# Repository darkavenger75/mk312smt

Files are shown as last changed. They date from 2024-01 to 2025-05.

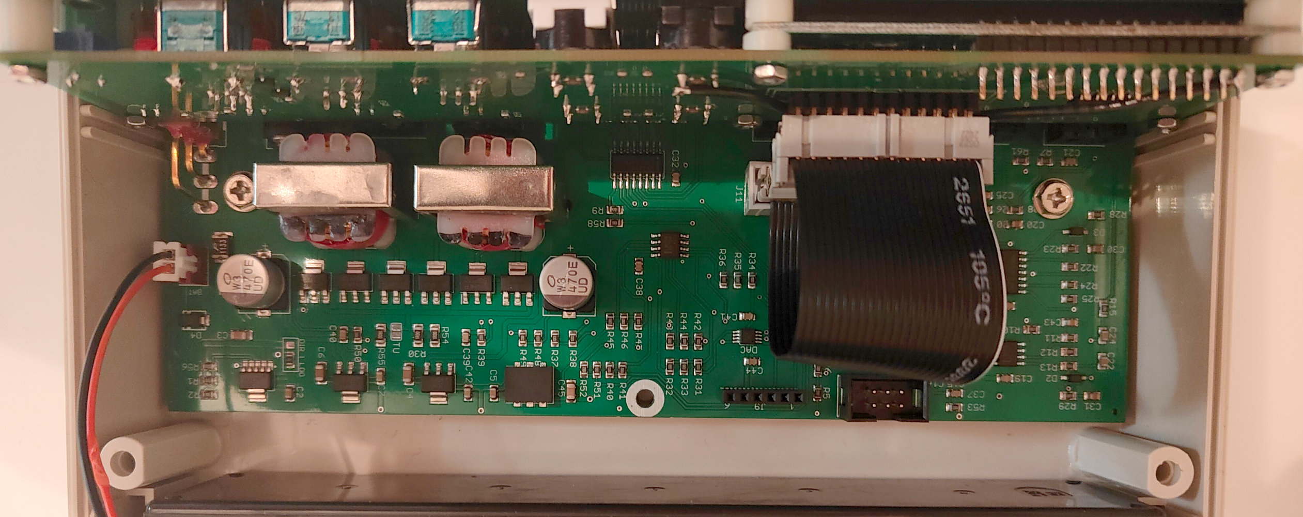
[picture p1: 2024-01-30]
images/mk312smt_int2.jpg

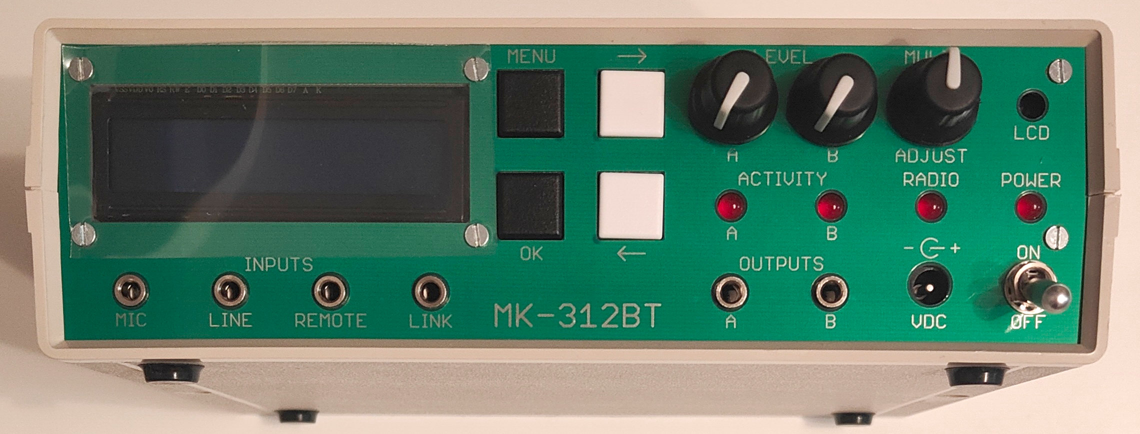
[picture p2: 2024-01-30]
images/mk312smt_front.jpg

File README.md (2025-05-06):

# mk-312 smt

## Introduction

A SMT version of the mk312-bt with several improvements

- More modern and efficient components in the power and output stage
- Input buttons more interference-proof to avoid the ATmega crashing
- And the best thing: someone like JLCPCB can do the assembly for you, you only need to add a few through-hole components and fit everything into the case. 

Main and control PCB are compatible with the THT versions, so that you can replace just one of them and keep the other PCB.

## Board ordering instructions 

PCB
- Default settings by JLCPCB work fine. Feel free to choose different color, etc. Lead-free recommended for the sake of the environment.

Assembly
- Economic, Bottom side (control PCB) / Top side (main PCB), as many PCBs as you wish. "Confirm Parts Placement" recommended. 
- Automatic selection of parts after uploading BOM and CPL worked well, but better check for obvious errors here and in part placement. 
- BOMs contain all components, including the THT ones. If you want to place the THT parts yourself just deselect them.

## Parts ordering information

You will in addition require
- Anything not on the PCB itself (button covers, knobs for pots, display + pin header).
- Any part your manufacturer did not have in stock. In case of JLCPCB this means especially the 42TU200 or 42TL004 transformers. Other parts missing you might pre-order to avoid additional effort. 
- 2x12P ribbon cable with connectors.
- A lead-acid battery of your choice. You can alternatively use a 12V LiFePO4 battery (with BMS), for that you need a matching charger (instead of the 15V power supply) and have to move the "jumper" (0R resistor) from "LDO" to "DIR" position to skip the voltage regulator. If you plan to use a LiFePO4 battery from the beginning (making the device much lighter) you can move the 0R resistor already when ordering and leave out V_REG (TPS73801), R1, R2, C2, C3, D1 from the beginning. These changes have been implemented in V2x which are now LiFePO4 only. 

## Board assembly Instructions

Nothing special here, just add the THT parts missing and mount the control panel to the front panel.

## Firmware

The firmware has not been modified, for instructions see the "firmware" folder. 

## Case

Fits in the stadard PACTEC case, see original BOM. 

## Update

- If the logic-level MOSFET IRLL2705 is not in stock at JLCPCB, it can be replaced by ZXMN4A06GTA or NDT3055L.
- The 5V DC-DC converter K7805MT-500R4 is no longer available. A version with a THT version has been added.
- If you like to keep using your 15V power supply with the LiFePO4 battery pack you can use V2b of the main PCB and the charger daughterboard.

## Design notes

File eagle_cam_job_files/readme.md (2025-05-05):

Please find the files required for PCB production and assembly here.
Do not forget the components (e.g. buttons and display) for the top side of the control PCB.
V1.3 Front Panel has a bit smaller cutout for the display, leaving less a gap. A display with outer dimensions 24*71 mm (many low-cost ones) fits. There are slightly larger displays, e.g. from Newhaven which are 26.5 mm high. Use version V1.3L for those.

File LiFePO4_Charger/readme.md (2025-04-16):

Daughterboard for the V2b main PCB.
LiFePO4 charger for the 4s battery pack so you can keep using your 15V power supply instead of using an external charger.

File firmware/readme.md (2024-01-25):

# MK312-BT Firmware

1. Set fuses for external 8 MHz crystal:
   
   avrdude -c usbasp-clone -p m16 -U lfuse:w:0xFF:m -U hfuse:w:0xD9:m
   
2. Flash any of the two firmware files, e.g. by

   avrdude -c usbasp-clone -p m16 -U "flash:w:HelloFriend.bin"

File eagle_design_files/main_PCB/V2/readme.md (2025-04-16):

5V DC-DC converter replaced by PTH version because of much better availability.
Version 2a with lower cost connectors and power switch. Version 2b has a connector for the LiFePO4 charger daughterboard.

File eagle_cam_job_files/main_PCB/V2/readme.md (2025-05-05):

5V DC-DC converter replaced by PTH version because of much better availability.
Version 2a with lower cost connectors and power switch (normally in stock at JLCPCB).
Version 2b has a connector for the LiFePO4 charger daughterboard.

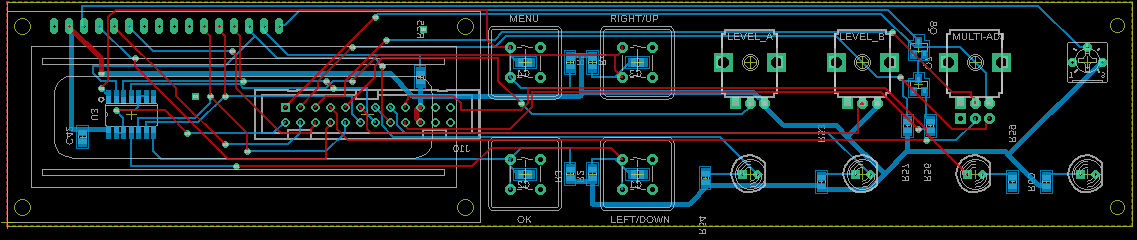
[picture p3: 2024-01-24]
eagle_design_files/control_PCB/mk312_control_Top.png

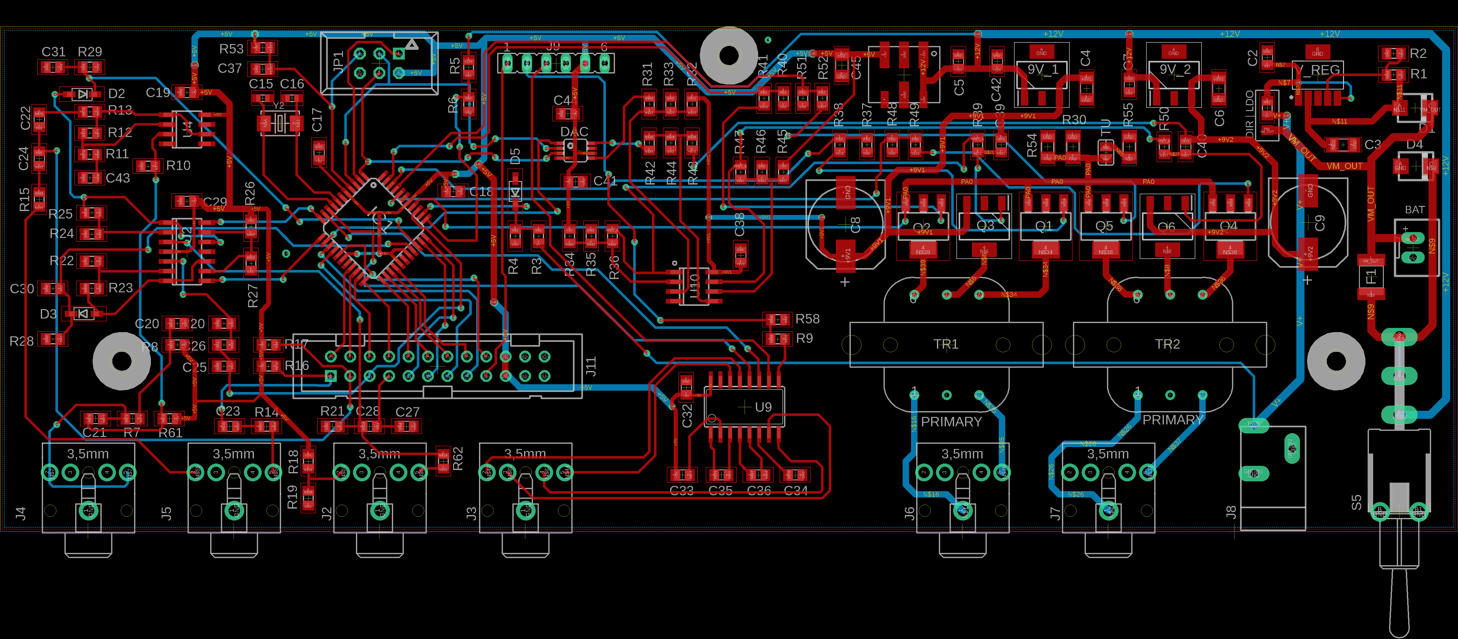
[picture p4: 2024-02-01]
eagle_design_files/main_PCB/mk312_smt_main_Top.png

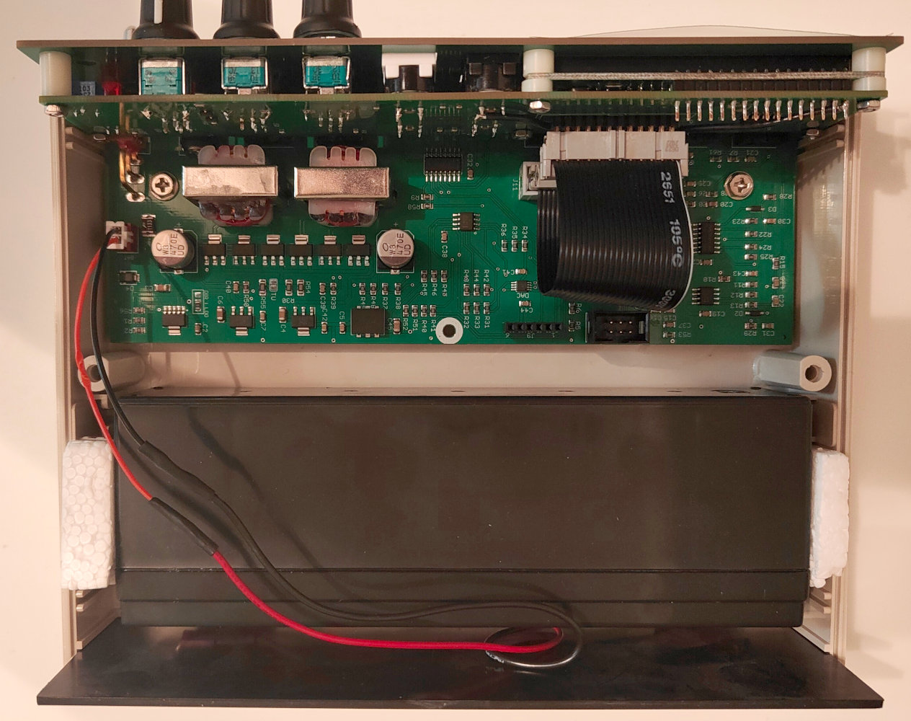
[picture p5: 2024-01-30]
images/mk312smt_int.jpg

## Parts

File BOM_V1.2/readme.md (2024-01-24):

Old BOM of version 1.2. Might contain additional useful information on the required THT components.

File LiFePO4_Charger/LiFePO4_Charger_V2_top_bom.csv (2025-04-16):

Comment | Designator | Footprint | LCSC Part #
4k7 | R10 | R0603 | C17673
LED_G | LED_G | 0805 | C2297
LED_R | LED_R | 0805 | C2296
1x6P | SV1 | 1x6P | C5333441
10uF | C3 | C0805 | C15850
10uH | L1 | FXL0630-100-M | C167223
16k | R4 | R0805 | C17490
22uF | C5 | C0805 | C45783
100nF | C1 C6 | C0805 | C49678
120R | R3 | R0603 | C22787
180k | R5 | R0603 | C22827
220nF | C2 | C0805 | C5378
250mR | RS1 RS2 | R1206 | C160921
AO3401A | Q1 | MICRO3 | C15127
B2B-XH-A-R(LF)(SN) | BAT | JST-XH-02-PACKAGE-LONG-PAD | C495685
SLM6900 | IC1 | TSSOP14 | C388595
SS54 | D1 D2 | SMA | C22452

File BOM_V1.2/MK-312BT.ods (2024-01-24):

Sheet: INFO
MK-312 BT V1.2 Information
Github Project Home : https://git.io/vMPVF
About
INFO is this Google Sheet - the latest copy of this document lives at http://tinyurl.com/mk312bt-info or https://goo.gl/Ia0wMW
FULLBOM consists of all items - sorted for sanity. Enter the number of units you want to produce in the top row and it will math for you.
MOUSERBOM1 contains items in FULL_BOM available from mouser and we select the "recommended" options . This BOM is for 1 UNIT.
NONMOUSER is a list of all the parts you cant get from Mouser with links to where you can get them from
RAWBOM is the output Eagle generates for the V1.1 schematic. This is used for cross checking the other documents.
MK-312BT V1.2 - Hardware Improvements over original ET-312B
1) Line input modified for matched frequency and level response on left and right channels.
2) Link I/O circuitry replaced with MAX-232CPE For better compatibility (True RS-232 Levels)
3) Provisions for Bluetooth radio, Radio takes over Link I/O when nothing is in the jack
4) New one piece front panel design where LCD, buttons, potentiometers, and LEDs are on the sub panel. Jacks and power switch on mainboard. Cleaner looking design with controls and jacks on 3/4" centers
5) Remote input added to facilitate DC response into B channel without compromising line audio input characteristics. Tip is voltage coming from remote 0-2 volts, Ring supplies 2 volts from a resistor divider internal to the unit. Sleeve is ground. The Remote is meant for the Audio 1 & 2 modes. External potentiometer and push button recommended for remote. Other SPST type of items can be used such as motion detectors with dry contact output or mercury switches.
6) Support for tri polar (+, GND, -) toys on the output channels
MK-312BT Hardware Jumper Settings
1) JP6 and JP7 [DISABLED BY DEFAULT]
Enabling JP6 and JP7 allow the use of tripolar (+, GND, -) toys on the corresponding channels by connecting the center tap of the transformer to the stereo jack
WARNING : ENABLING JP6 and JP7 will cause mono plug toys to short the transformer !!
MK-312BT Hardware Assembly Notes / Tips - PLEASE READ -
1) Trim Potentiometer knobs to correct length
2) Use black permanent marker to black out front panel hole walls
3) Cut the tabs off of the base of the pots so the board sits flush with the display facade
4) To correctly fit LCD - solder header to LCD board first. Next insert LCD panel into front panel daughter board. Then put screws on front panel facade and finger tighten M2.5 screws first. Adjust positions as needed so everything lines up and sits well. Finally soldering LCD header to front panel daughter board.
5) Make sure Pin 32 (LED2) on the HC-05 module is actually soldered and making connection to the ZS-040 break out board or "Radio" LED may not function on the front panel
6) Be very careful not to bridge pins when soldering the LM 2941 (U14). Apply heat to 1 pad only and carefully apply solder. If a bridge occurs - remove the IC, clean the pads throughly with flux and solder wick and then retry. Pins 2 and 3 can be bridged because they are both ground. Ensure that no other pins are bridged. Check with multimeter continuity tester for bridges before power on!
8) Make sure to check the orientation of all electrolytic caps. (+) indicates the positive and a solid white "|" indicates the negative .
9) MAKE SURE YOUR POWER PLUG IS CENTER POSITIVE OR THINGS WILL GO BADLY. If you fuck up and plug in a reversed polarity supply - replace electrolytic caps C1 and C4.
10) Please remember to adjust the LCD contrast potentiometer - if incorrectly set the unit and backlight will power on but the interface will not be displayed.
11) Place transformers with P facing the output jacks (yes we are using the transformers "backwards" if you follow orientation given in the transformer datasheet )
12)Trim pins of 4066 IC (U3) Socket on the front panel board flush before soldering so buttons can clear. If the buttons still interfere, carefully disassemble the button and cut off the bit of the plastic housing that interferes with the 4066 IC socket pins.
Changes made in buttshock-et312-frankenbutt f005 over original ET 312B V1.5/V1.6 firmware https://git.io/vMoHG
F005 Patches the following in addition to the stock firmware
1) changeversion: changes startup message from v1.6 to f005
2) unifyboxes: allow 1.5 and 1.6 boxes to share the same firmware
3) removerandomxor: box will always pick 0 as it's xor communication key
4) serialdumpmemory: box will allow serial to dump more of the flash memory on request
5) fixknobscaling: A and B levels now display smoothly 0-99 with no missing numbers
6) newmenu; adds a new sub menu "More Options", moves Link Slave to that menu
7) hookmain: adds a new mode "Random 3" kind of a combination of torment and random1 to the new options menu, adds a new mode "Random 4" which turns on with a random mode for 40ish seconds, then off for 20ish seconds
Modifying and Flashing Firmware onto ET312-BT
1) We are using an external 8mhz crystal instead of the internal RC oscillator that the original uses. We need to set the fuses to enable this. LOW FUSE : 0xFF HIGH FUSE : 0xDB
2) A patched version of buttshock-et312-frankenbutt-f005 is recommended .
3) Obtain or modify a copy of the firmware and flash the result onto the AVR.
5) If you dont want to use an external crystal - we need to set the calibration byte for the internal oscillator. If programming a blank chip you first need to read the calibration bytes of that part (i.e. using avrdude -t “dump calibration” the fourth byte is the calibration byte for 8MHz or use atmel studio to read the oscillator calibration byte). Then program that byte into 0x3fff in your firmware. These bytes will differ on different chips even from the same batch. The firmware reads that byte to set OSCCAL on startup. If the byte is inaccurate various problems and failures will occur related to timing, interrupts, and serial communication. Just use an external crystal dammit.
Errata and and Changes made from V1.0 to V1.1
1) C25 and C27 are mislabeled on the board, 1000pF is the correct value
2) R20 and R21 are mislabeled on the board, 100K is the correct value
3) R14 and R15 are mislabeled on the board, 1K is the correct value
4) R20 and R21 are mislabeled on the board, 20K is the correct value
5) Do not populate R9 100K
6) Do not populate R1B 12K
Errata and and Changes made from V1.1 to V1.2
1) Fixed routing error on display board.
2) Removed JP3 because pointless.
3) Changed size of electrolytics to make things fit a bit nicer.
Images of V1.2 MK 312BT
TODO : Changes to make for V1.3 MK 312BT
1) LM 2941 footprint to make it easier to solder without bridging
2) Move 4066 IC to better place.

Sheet: FULLBOM
Number of Units Produced : | 1
Designator | Description | Quantity per Unit | Total Quantity | Supplier | Supplier Part Number | Alternate Part | Notes
R55 | RES 47R | 1 | 1 | Mouser | 660-MF1/4DC47R0F
R53,R54,R59,R60 | RES 390R | 4 | 4 | Mouser | 660-MF1/4DCT52R3900F
C10,C11,C12,C13,C14,C17,C18,C19,C2,C21,C22,C23,C24,C26,C28,C29,C3,C32,C37,C38,C39,C40,C41,C42,C43,C44,C9 | CAP 0.1uF (0.1" spacing) 50V | 27 | 27 | Mouser | 80-C320C104K5R
R30 | RES 0.5R 1/2W | 1 | 1 | Mouser | 660-CF1/2CT52RR50J
R2 | RES 1.2K | 1 | 1 | Mouser | 660-MF1/4DCT52R1201F
R18, R56,R57 | RES 1.5K | 3 | 3 | Mouser | 660-MF1/4DCT52R1501F
C4,C5 | 1000uF 16V minimum | 2 | 2 | Mouser | 647-UPW1E102MPD6
R10,R20,R21,R27,R28,R29,R3,R31,R32,R33,R34,R36,R37,R40,R42,R43,R44,R45,R47,R48,R51 | RES 100K | 21 | 21 | Mouser | 660-MF1/4DC1003F
R38,R39,R41,R49,R5,R50,R52,R58 | RES 10K | 8 | 8 | Mouser | 660-MF1/4DCT52R1002F | 660-MF1/4DC1002F
C8 | CAP 10uF | 1 | 1 | Mouser | 647-USV1H100MFD1TP
C1 | CAP 10uF CER | 1 | 1 | Mouser | 810-FG11X7R1H106KRT6 |  | Ceramic Cap in case of reverse voltage dc supply
R1A | RES 12K | 1 | 1 | Mouser | 660-MF1/4DCT52R1202F
C15,C16 | CAP 18pF | 2 | 2 | Mouser | 80-C315C180J1G
F1 | 1A POLYFUSE | 1 | 1 | Mouser | 650-LVR100S
R14,R15,R19, | RES 1K | 3 | 3 | Mouser | 660-MF1/4DCT52R1001F
R12,R23,R25,R26 | RES 1M | 4 | 4 | Mouser | 660-MF1/4DCT52R1004F
D1 | DIODE 1N4004 | 1 | 1 | Mouser | 621-1N4004
D2,D3 | DIODE 1N4148 | 2 | 2 | Mouser | 512-1N4148
C25,C27 | CAP 1nF (0.1" spacing) | 2 | 2 | Mouser | 80-C315C102K1G
C20,C30,C31,C33,C34,C35,C36 | CAP 1uF (0.1" spacing) | 7 | 7 | Mouser | 80-C315C105K3R
R35,R46 | RES 200K | 2 | 2 | Mouser | 660-MF1/4DCT52R2003F
R11,R16,R17,R22,R24,R4 | RES 20K | 6 | 6 | Mouser | 660-MF1/4DCT52R2002F
J10,J11 | PAK100/2500-24 - 2425- 3M WALL HEADER | 2 | 2 | Mouser | 517-N2524-6002RB
Q7,Q8 | TRANS. 2N3904 | 2 | 2 | Mouser | 512-2N3904BU
R6 | RES 3.3K | 1 | 1 | Mouser | 660-MF1/4DCT52R3301F
R7,R8,R9 | RES 4.7K | 3 | 3 | Mouser | 660-MF1/4DCT52R4701F
U3 | CD4066N | 1 | 1 | Mouser | 595-CD4066BE
TR1,TR2 | 42TL004 | 2 | 2 | Mouser | 42TL004-RC
C6,C7 | CAP 470uF 16V | 2 | 2 | Mouser | 647-UHE1E471MPD
R13 | RES 47K | 1 | 1 | Mouser | 660-MF1/4DCT52R4702F
U13 | VREG 7805T | 1 | 1 | Mouser | 511-L7805CV | 511-L7805ACP | Alternate part is better thermally
U11,U12 | VREG 7809TV | 2 | 2 | Mouser | 511-L7809CV
XTAL1 | 8MHZ XTAL HC-49S | 1 | 1 | Mouser | 717-9B-8.000MEEJ-B
U1 | ATMEGA 16P | 1 | 1 | Mouser | 556-ATMEGA16A-PU | http://www.digikey.com/short/3fb4z5
LCD1 | LCD HD44780LCD-1602 | 1 | 1 | Mouser | 763-0216K1Z-NSW-BBW | 763-0216K1Z-NSW-FBW
Q3,Q6 | MOSFET IRF9Z24 | 2 | 2 | Mouser | 942-IRF9Z24NPBF
Q1,Q2,Q4,Q5 | MOSFET IRL520N | 4 | 4 | Mouser | 942-IRL520NPBF
JP1 | ISP 6 PIN | 1 | 1 | Mouser | 571-5-146254-3
U14 | LM2941 | 1 | 1 | Mouser | 926-LM2941CT/NOPB
U2 | LM324N | 1 | 1 | Mouser | 595-LM324N | 595-LM324NE3
U10,U4 | LM358N | 2 | 2 | Mouser | 512-LM358N
U8A (OPTIONAL - RECOMMEND USING U8B INSTEAD) | MAX548 | 0 | 0 | Mouser | 700-MAX548ACPA |  | For V1.5 and below firmware.We suggest using U8B LTC1661 purchased from Digikey (see below)
LED1,LED2,LED3,LED4 | 5MM LED | 4 | 4 | Mouser | 606-4304H1
U9 | MAX232 | 1 | 1 | Mouser | 700-MAX232CPE
SOCKET FOR U2,U3 | DIL 14 IC SOCKET | 2 | 2 | Mouser | 517-4814-3004-CP
SOCKET FOR U9 | DIL 16 IC SOCKET | 1 | 1 | Mouser | 517-4816-3004-CP
SOCKET FOR U1 | DIL 40 IC SOCKET | 1 | 1 | Mouser | 575-11041640410010
SOCKET FOR U10,U4,U8(A/B) | DIL 8 IC SOCKET | 4 | 4 | Mouser | 571-1-2199298-2
JP6,JP7 | 2x1 SIP HEADER 0.1" | 2 | 2 | Mouser | 571-5-146285-2
JUMPER | 0.1" JUMPER | 3 | 3 | Mouser | 571-382811-6
VR1, VR2 | ALPS 9mm 10K Pot | 2 | 2 | Mouser | 688-RK09L1140A2U
VR3 | ALPS 9mm 10K Dual Gang Pot | 1 | 1 | Mouser | 688-RK09L1240A12
VR4 | Bourns 3362P 10K Pot | 1 | 1 | Mouser | 3362P-1-103LF
S1,S2,S3,S4 | Buttons | 4 | 4 | Mouser | 611-D6C90F2LFS
J2,J3,J4,J5,J6,J7 | 3.5mm stereo jack | 6 | 6 | Mouser | 806-STX-3100-5NB
J8 | 2.1/5.5mm DC jack | 1 | 1 | Mouser | 490-PJ-002A
S5 | Toggle Switch with safety actuator | 1 | 1 | Mouser | 611-7101K2AV2BE | 611-7101K2AV2QE
J9 | Radio Header | 1 | 1 | Mouser | 538-90147-1206
PACTEC Case | Case | 1 | 1 | Mouser | 616-63025-510-000 | Suggest buying directly from PACTEC or sourcing a compatible case elsewhere http://bit.ly/2iuAHbB . UK SOURCE : http://uk.rs-online.com/web/p/consoles-desktop-enclosures/1047312/
Gray button covers | Button Cover | 2 | 2 | Mouser | 611-BTND610F | 611-BTND690F
White button covers | Button Cover | 2 | 2 | Mouser | 611-BTND600F
LCD HEADER | LCD Header | 1 | 1 | Mouser | 710-61301611121
KNOB | Potentiometer KNOB | 3 | 3 | Mouser | 450-BA761
BAT1 (Recommended Option) | Lead Acid Battery 2.5AH | 1 | 1 | Mouser | 547-PS-1220 | UK SOURCE http://uk.rs-online.com/web/p/lead-acid-rechargeable-batteries/5375444/
BAT1 (Option) | Lead Acid Battery 1.4AH | 0 | 0 | Mouser | 547-PS-1212
BAT 1 LUGS | Lugs For Connecting to BAT1 | 2 | 2 | Mouser | 534-8291 |  | Crimp on Lugs for Battery
Power Supply 15V (Option) | 15V, > 1A , 5.5MM OD Plug | 0 | 0 | Mouser | 709-GST25U15-P1J
Power Supply 18 V (Recommended Option) | 18V, 1A , 5.5MM OD Plug | 1 | 1 | Mouser | 709-GST18U18-P1J |  | Suggest using 18V version to give linear regulator a bit more headroom . 15V will *just barely* work
IDC connectors for ribbon cable | Ribbon Cable Connector(or buy a ready made cable) | 2 | 2 | Mouser | 517-8924 |  | Suggest sourcing a ready made cable . See misc hardware below
24 conductor ribbon cable | Bare Ribbon Cable (or buy a ready made cable) | 1 | 1 | Mouser | 517-3365/24-100 |  | See above.
Radio | HC-05 Bluetooth Module | 1 | 1 | Amazon | HC-05 (multiple amazon vendors) |  | http://amzn.to/2iiOXz6
U8B | LTC1661 (For V1.6 and above firmware) | 1 | 1 | Digikey | LTC1661CN8#PBF-ND |  | This is the suggested DAC
J1 T Connector (Deans Connector)- DNF (Unless you want to , then F away) | 12V Battery Connector | 1 | 1 | Hobbyking | SKU: 015000231-0 |  | http://bit.ly/2jpP4gQ
MISC HARDWARE
Ribbon Cable 24 pin, 2.54mm pitch IDC. | Ribbon Cable | 1 | 1 | Amazon | B01BGNLPX0 |  | http://amzn.to/2jp34ay
#4 x 1/4" sheet metal screw (Main board to case) | Screw | 2 | 2 | McMaster-Carr | 90190A106 |  | http://bit.ly/2jCJuVR
M2.5 x 20mm socket head screw (Front panel screws) | Screw | 6 | 6 | McMaster-Carr | 91290A108 |  | http://bit.ly/2jhEohH
M2.5 nut (Front panel nut) | Screw | 22 | 22 | McMaster-Carr | 90591A270 |  | http://bit.ly/2jpf0Jq
18 Gauge Wire : | Battery Leads (quantity ft) | 5 | 5 | McMaster-Carr | 8054T15 |  | http://bit.ly/2jCHwER
Heat Shrink | Heat Shrink Tubing | 1 | 1 | McMaster-Carr | 7496K43 |  | http://bit.ly/2jYteSl

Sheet: MOUSERBOM1
Designator | Description | Quantity per Unit | Supplier | Supplier Part Number | Mfg Part Number | Alternate Part
R55 | RES 47R | 1 | Mouser | 660-MF1/4DC47R0F | MF1/4DC47R0F
R53,R54,R59,R60 | RES 390R | 4 | Mouser | 660-MF1/4DCT52R3900F | MF1/4DCT52R3900F
C10,C11,C12,C13,C14,C17,C18,C19,C2,C21,C22,C23,C24,C26,C28,C29,C3,C32,C37,C38,C39,C40,C41,C42,C43,C44,C9 | CAP 0.1uF (0.1" spacing) 50V | 27 | Mouser | 80-C320C104K5R | C320C104K5R5TA
R30 | RES 0.5R 1/2W | 1 | Mouser | 660-CF1/2CT52RR50J | CF1/2CT52RR50J
R2 | RES 1.2K | 1 | Mouser | 660-MF1/4DCT52R1201F | MF1/4DCT52R1201F
R18, R56,R57 | RES 1.5K | 3 | Mouser | 660-MF1/4DCT52R1501F | MF1/4DCT52R1501F
C4,C5 | 1000uF 16V minimum | 2 | Mouser | 647-UPW1E102MPD6 | UPW1E102MPD6
R10,R20,R21,R27,R28,R29,R3,R31,R32,R33,R34,R36,R37,R40,R42,R43,R44,R45,R47,R48,R51 | RES 100K | 21 | Mouser | 660-MF1/4DC1003F | MF1/4DC1003F
R38,R39,R41,R49,R5,R50,R52,R58 | RES 10K | 8 | Mouser | 660-MF1/4DC1002F | MF1/4DC1002F | 660-MF1/4DCT52R1002F
C8 | CAP 10uF | 1 | Mouser | 647-USV1H100MFD1TP | USV1H100MFD1TP
C1 | CAP 10uF CER | 1 | Mouser | 810-FG11X7R1H106KRT6 | FG11X7R1H106KRT06
R1A | RES 12K | 1 | Mouser | 660-MF1/4DCT52R1202F | MF1/4DCT52R1202F
C15,C16 | CAP 18pF | 2 | Mouser | 80-C315C180J1G | C315C180J1G5TA
F1 | 1A POLYFUSE | 1 | Mouser | 650-LVR100S | LVR100S
R14,R15,R19, | RES 1K | 3 | Mouser | 660-MF1/4DCT52R1001F | MF1/4DCT52R1001F
R12,R23,R25,R26 | RES 1M | 4 | Mouser | 660-MF1/4DCT52R1004F | MF1/4DCT52R1004F
D1 | DIODE 1N4004 | 1 | Mouser | 621-1N4004 | 1N4004-T
D2,D3 | DIODE 1N4148 | 2 | Mouser | 512-1N4148 | 1N4148
C25,C27 | CAP 1nF (0.1" spacing) | 2 | Mouser | 80-C315C102K1G | C315C102K1G5TA
C20,C30,C31,C33,C34,C35,C36 | CAP 1uF (0.1" spacing) | 7 | Mouser | 80-C315C105K3R | C315C105K3R5TA
R35,R46 | RES 200K | 2 | Mouser | 660-MF1/4DCT52R2003F | MF1/4DCT52R2003F
R11,R16,R17,R22,R24,R4 | RES 20K | 6 | Mouser | 660-MF1/4DCT52R2002F | MF1/4DCT52R2002F
J10,J11 | PAK100/2500-24 - 2425- 3M WALL HEADER | 2 | Mouser | 517-N2524-6002RB | N2524-6002RB
Q7,Q8 | TRANS. 2N3904 | 2 | Mouser | 512-2N3904BU | 2N3904BU
R6 | RES 3.3K | 1 | Mouser | 660-MF1/4DCT52R3301F | MF1/4DCT52R3301F
R7,R8,R9 | RES 4.7K | 3 | Mouser | 660-MF1/4DCT52R4701F | MF1/4DCT52R4701F
U3 | CD4066N | 1 | Mouser | 595-CD4066BE | CD4066BE
TR1,TR2 | 42TL004 | 2 | Mouser | 42TL004-RC | 42TL004-RC
C6,C7 | CAP 470uF 16V | 2 | Mouser | 647-UHE1E471MPD | UHE1E471MPD
R13 | RES 47K | 1 | Mouser | 660-MF1/4DCT52R4702F | MF1/4DCT52R4702F
U13 | VREG 7805T | 1 | Mouser | 511-L7805CV | L7805CV | 511-L7805ACP
U11,U12 | VREG 7809TV | 2 | Mouser | 511-L7809CV | L7809CV
XTAL1 | 8MHZ XTAL HC-49S | 1 | Mouser | 717-9B-8.000MEEJ-B | 9B-8.000MEEJ-B
U1 | ATMEGA 16P | 1 | Mouser | 556-ATMEGA16A-PU | ATMEGA16A-PU | 556-ATMEGA16L-8PU ELSE SEE DIGIKEY ON NONMOUSER
LCD1 | LCD HD44780LCD-1602 | 1 | Mouser | 763-0216K1Z-NSW-BBW | NHD-0216K1Z-NSW-FBW-L | 763-0216K1Z-NSW-FBW
Q3,Q6 | MOSFET IRF9Z24 | 2 | Mouser | 942-IRF9Z24NPBF | IRF9Z24NPBF
Q1,Q2,Q4,Q5 | MOSFET IRL520N | 4 | Mouser | 942-IRL520NPBF | IRL520NPBF
JP1 | ISP 6 PIN | 1 | Mouser | 571-5-146254-3 | 5-146254-3
U14 | LM2941 | 1 | Mouser | 926-LM2941CT/NOPB | LM2941CT/NOPB
U2 | LM324N | 1 | Mouser | 595-LM324NE3 | LM324NE3 | 595-LM324N
U10,U4 | LM358N | 2 | Mouser | 512-LM358N | LM358N
U8A | MAX548 (For V1.5 and below firmware) suggest using LTC1661 purchased from Digikey (see end of sheet) | 0 | Mouser | 700-MAX548ACPA | MAX548ACPA+
LED1,LED2,LED3,LED4 | 5MM LED | 4 | Mouser | 606-4304H1 | 4304H1
U9 | MAX232 | 1 | Mouser | 700-MAX232CPE | MAX232CPE
SOCKET FOR U2,U3 | DIL 14 IC SOCKET | 2 | Mouser | 517-4814-3004-CP | 4814-3004-CP
SOCKET FOR U9 | DIL 16 IC SOCKET | 1 | Mouser | 517-4816-3004-CP | 4816-3004-CP
SOCKET FOR U1 | DIL 40 IC SOCKET | 1 | Mouser | 575-11041640410010 | 110-41-640-41-001000
SOCKET FOR U10,U4,U8(A/B) | DIL 8 IC SOCKET | 4 | Mouser | 571-1-2199298-2 | 1-2199298-2
JP6,JP7 | 2x1 SIP HEADER 0.1 | 2 | Mouser | 571-5-146285-2 | 5-146285-2
VR1, VR2 | ALPS 9mm 10K Pot | 2 | Mouser | 688-RK09L1140A2U | RK09L1140A2U
VR3 | ALPS 9mm 10K Dual Gang Pot | 1 | Mouser | 688-RK09L1240A12 | RK09L1240A12
VR4 | Bourns 3362P 10K Pot | 1 | Mouser | 3362P-1-103LF | 3362P-1-103LF
S1,S2,S3,S4 | Buttons | 4 | Mouser | 611-D6C90F2LFS | D6C90 F2 LFS
J2,J3,J4,J5,J6,J7 | 3.5mm stereo jack | 6 | Mouser | 806-STX-3100-5NB | STX-3100-5NB
J8 | 2.1/5.5mm DC jack | 1 | Mouser | 490-PJ-002A | PJ-002A
S5 | Toggle Switch with safety actuator | 1 | Mouser | 611-7101K2AV2BE | 7101K2AV2BE | 611-7101K2AV2QE
J9 | Radio Header | 1 | Mouser | 538-90147-1206 | 90147-1206
Gray button covers | Button Cover | 2 | Mouser | 611-BTND610F | BTND610F | 611-BTND690F
White button covers | Button Cover | 2 | Mouser | 611-BTND600F | BTN D6 00 F
LCD HEADER | LCD Header | 1 | Mouser | 710-61301611121 | 61301611121
Knob | Potentiometer Knob | 3 | Mouser | 450-BA761 | BA761
BAT1 | Lead Acid Battery | 1 | Mouser | 547-PS-1220 | PS-1220
BAT1 Lugs | Crimp Lubs for BAT1 | 2 | Mouser | 534-8291 | 534-8291
Power Supply | 18V, 1A .5.5mm OD plug | 1 | Mouser | 709-GST18U18-P1J | GST18U18-P1J | 709-GST25U15-P1J

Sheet: NONMOUSER
Parts Not Sourced from Mouser
Part | Quantity
Bluetooth Radio HC - 05 | 1
Amazon : http://amzn.to/2l0UEoj
LTC 1661 DAC | 1
Digikey LTC1661CN8#PBF-ND : http://www.digikey.com/short/3rh0zq
LM324N (Digikey if mouser is out of stock)
Digikey : http://www.digikey.com/short/3fb4md | 1
ATMEGA 16 (Digikey if mouser is out of stock)
Digikey : http://www.digikey.com/short/3fb4z5 | 1
Ribbon Cable 24 pin, 2.54mm pitch IDC. | 1
Amazon : http://amzn.to/2jp34ay
18 Gauge Wire : | 5ft
McMaster-Carr: http://bit.ly/2jCHwER
Heat Shrink Tubing: | 1 pack
McMaster-Carr : http://bit.ly/2jYteSl
#4 x 1/4" sheet metal screw (Main board to case) | 2
McMaster-Carr : http://bit.ly/2jCJuVR
M2.5 x 20mm socket head screw (Front panel screws) | 6
McMaster-Carr : http://bit.ly/2jhEohH
M2.5 nut (Front panel nut) | 22
McMaster-Carr : http://bit.ly/2jpf0Jq
T Connector (Deans Connector - OPTIONAL) | 1
Hobbyking : http://bit.ly/2jpP4gQ
Lead Acid Battery
Digikey : https://www.digikey.com/short/3ff7t4
Pactec Case | 1
Allied : http://www.alliedelec.com/pactec-cm86-225-000-k/70080019/
Pactec : https://www.pactecenclosures.com/product-detail.php?productid=72&classid=26&seriesid=45
UK Souce RS Online : http://uk.rs-online.com/web/p/consoles-desktop-enclosures/1047312/
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

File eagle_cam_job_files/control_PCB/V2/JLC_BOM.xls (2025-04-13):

Comment | Designator | Footprint | JLCPCB Part #
MMBT3904 | Q7,Q8 | SOT23 | C20526
390 | R53,R54,R59,R60 | R0805 | C17655
Z-S311024S1GK1A | J10 | PAK100/2500-24 | C221083
4066D | U3 | SO14 | C5628
1.5K | R56,R57 | R0805 | C4310
0.1uF | C42 | C0805 | C49678
100k | R2,R3,R4,R5 | R0805 | C149504
100pF | C1,C2,C3,C4 | C0805 | C1790
47 | R1 | R0805 | C17714
D6C90F2LFS | LEFT/DOWN MENU OK RIGHT/UP | DTE6K | C2689630
HD44780LCD-1602 | LCD1 | LCD1602
3362P-1-103LF | VR4 | B25P | C58159
TLHR4605 | LED1,LED2,LED3,LED4 | LED5MM | C5899447
RK09L1140A5L | LEVEL_A LEVEL_B | 9MM_SNAP-IN_POT | C7419101
RK09L1240015 | MULTI-ADJ | DUAL_9MM_SNAP-IN_POT | C7471751

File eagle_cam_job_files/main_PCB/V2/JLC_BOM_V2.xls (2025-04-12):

Comment | Designator | Footprint | JLCPCB Part #
0.1uF | C17,C18,C19,C21,C26,C28,C29,C32,C37,C38,C39,C40,C41,C44 | C0805 | C49678
0.47uF | C7,C42 | C0805 | C13967
1.5K | R18 | R0805 | C4310
100K | R3,R10,R20,R21,R27,R28,R29,R31,R32,R33,R34,R36,R37,R40,R42,R43,R44,R45,R47,R48,R51,R61 | R0805 | C149504
10k | R38,R39,R41,R49,R50,R52,R58,R53,R5 | R0805 | C17414
10uF | C1 | C0805 | C15850
1K | R14,R15,R19,R62 | R0805 | C17513
1M | R12,R23,R25,R26 | R0805 | C17514
1nF | C25,C27 | C0805 | C46653
1R | R30,R54,R55 | R1206 | C17928
1uF | C20,C22,C23,C24,C30,C31,C33,C34,C35,C36,C43 | C0805 | C28323
2.2K | R7,R8 | R0805 | C17520
200K | R35,R46 | R0805 | C17539
20K | R4,R11,R16,R17,R22,R24 | R0805 | C4328
20pF | C15,C16 | C0603 | C1648
22uF | C3,C4,C6 | C1206 | C12891
3.3k | R6 | R0805 | C26010
321008SG0ABK00A01 | JP1 | 057-006-1 | C5372863
4.7K | R9,R13 | R0805 | C17673
42TU200 | TR1,TR2 | 42TU
470uF | C8,C9 | 150CLZ-1010 | C125983
7101K2AV2BE | S5 | LPV-1 | C2799631
8MHZ | Y2 | X2-SMD-5.0X3.2X1.3MM | C115962
B2B-XH-A-R(LF)(SN) | BAT | JST-XH-02-PACKAGE-LONG-PAD | C495685
BSP170PH6327 | Q3,Q6 | SOT230P700X180-4N | C75283
D_1N4148W_ST_SOD123 | D2,D3,D5 | SOD123 | C81598
LM2940IMP-9.0/NOPB | 9V_1,9V_2 | SOT230P700X180-4N | C471057
LM324DT | U2 | SO14 | C71035
LM358DR2G | U4,U10 | SO08 | C7950
LTC1661CMS | DAC | MSOP8 | C676323
MAX232ESE+T | U9 | SOP-16 | C26860
MEGA16-A | IC1 | TQFP44 | C5658
N-HEXFET-2D_SOT232-IRLL2705 | Q1,Q2,Q4,Q5 | SOT223 | C151552
PJ-002A | J8 | POWER_JACK_SLOT | C3096082
SMD1812P110TF | F1 | CT/CN1812 | C495358
SS34 | D4 | SMA | C8678
STX-3100-5NB | J2,J3,J4,J5,J6,J7 | STX3100 | C19843187
K7805-500 | REG5 | SIP-3 | C19188491
X6511FV-06-C85D32 | J9 | FE06 | C718239
XZ-S311024S1GK1A | J11 | PAK100/2500-24 | C221083

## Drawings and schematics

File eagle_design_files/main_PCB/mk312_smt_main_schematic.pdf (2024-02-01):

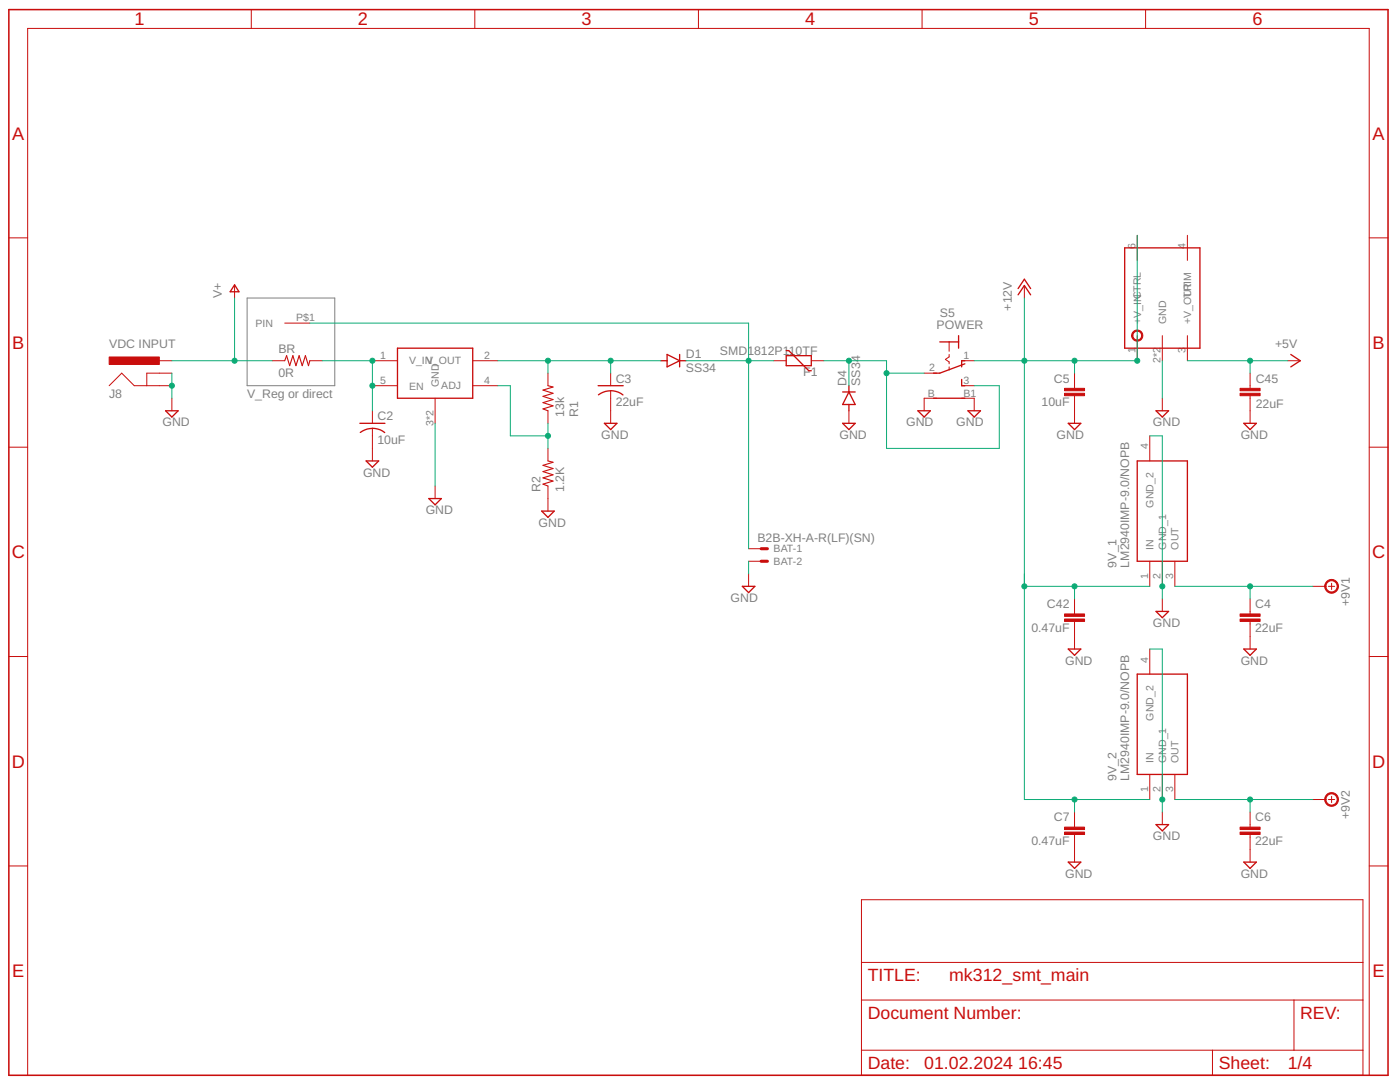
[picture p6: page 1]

V_Reg or direct VDC INPUT

Document Number: | REV:

Date: 01.02.2024 16:45 | Sheet: 1/4

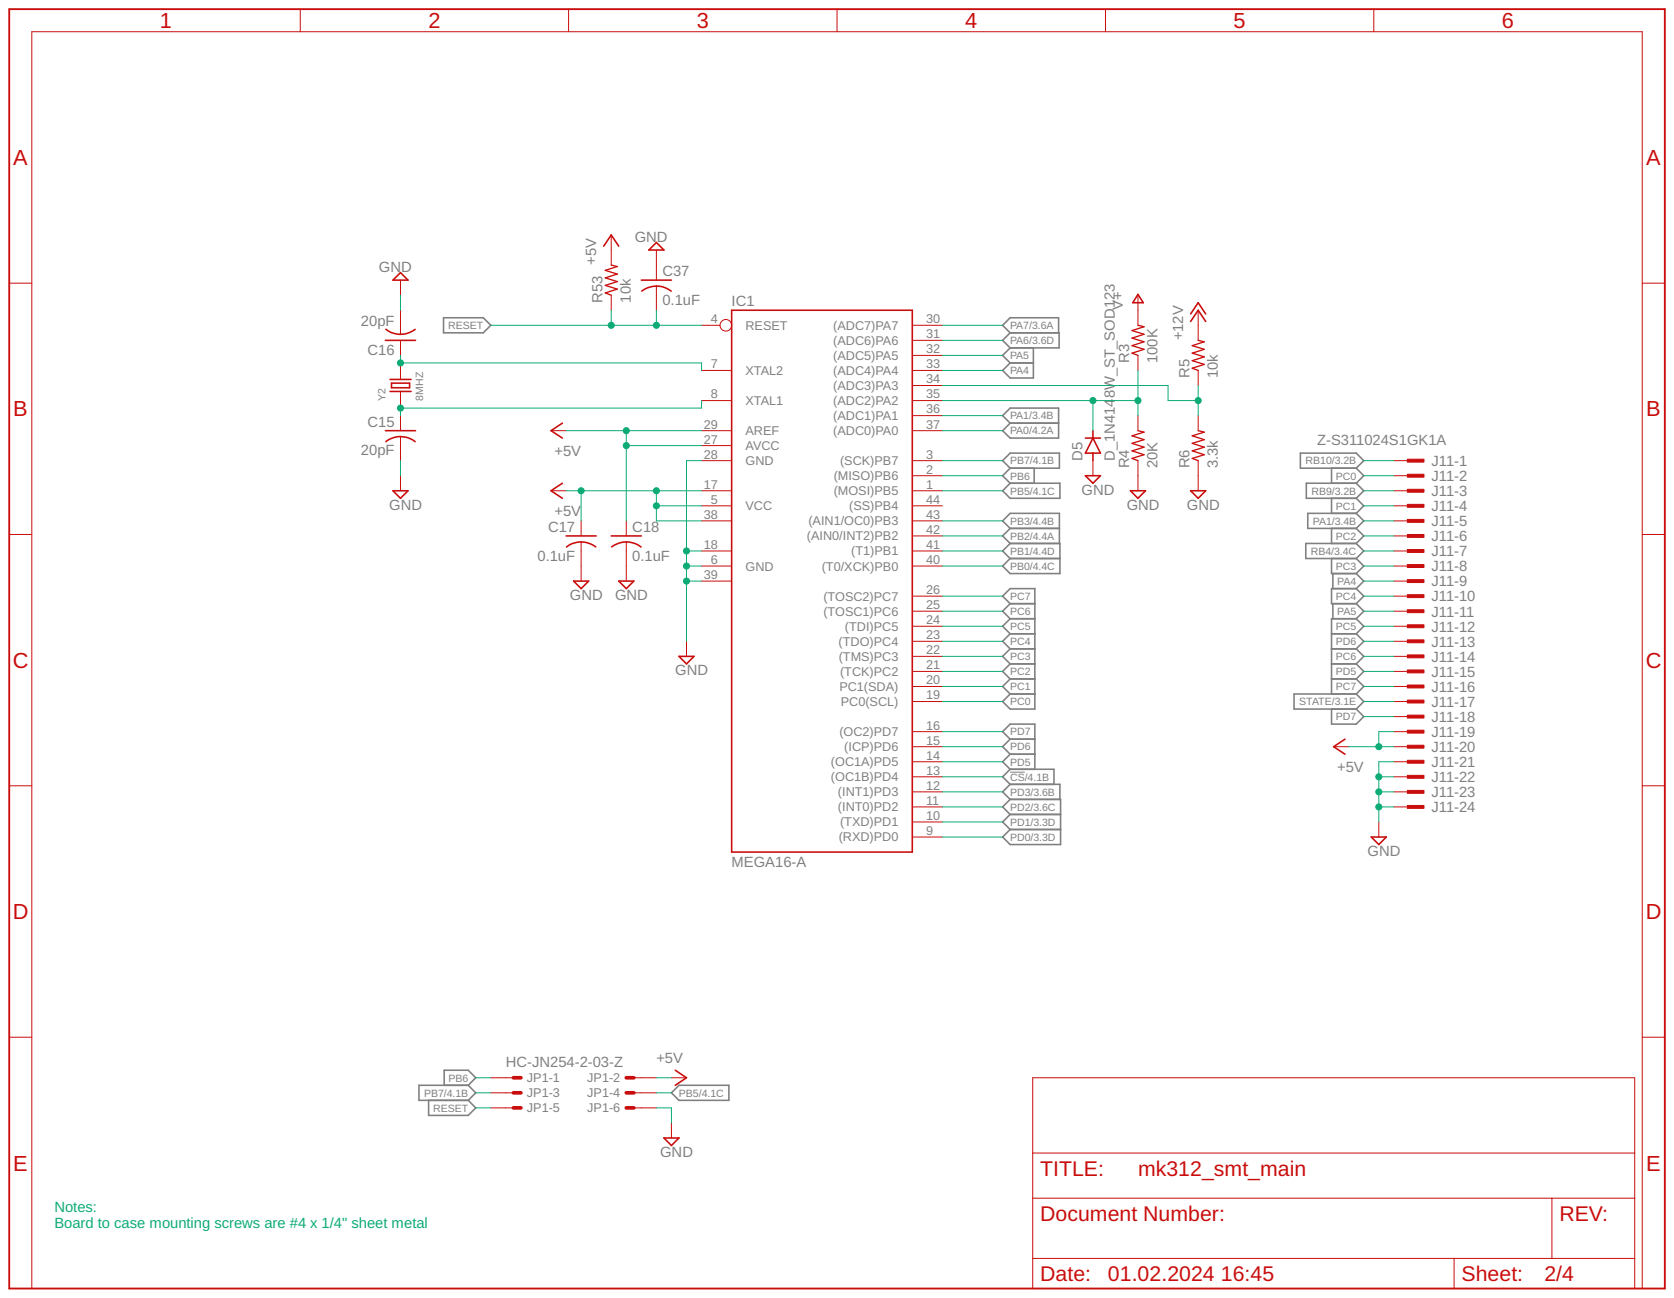
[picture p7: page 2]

Notes: Board to case mounting screws are #4 x 1/4" sheet metal

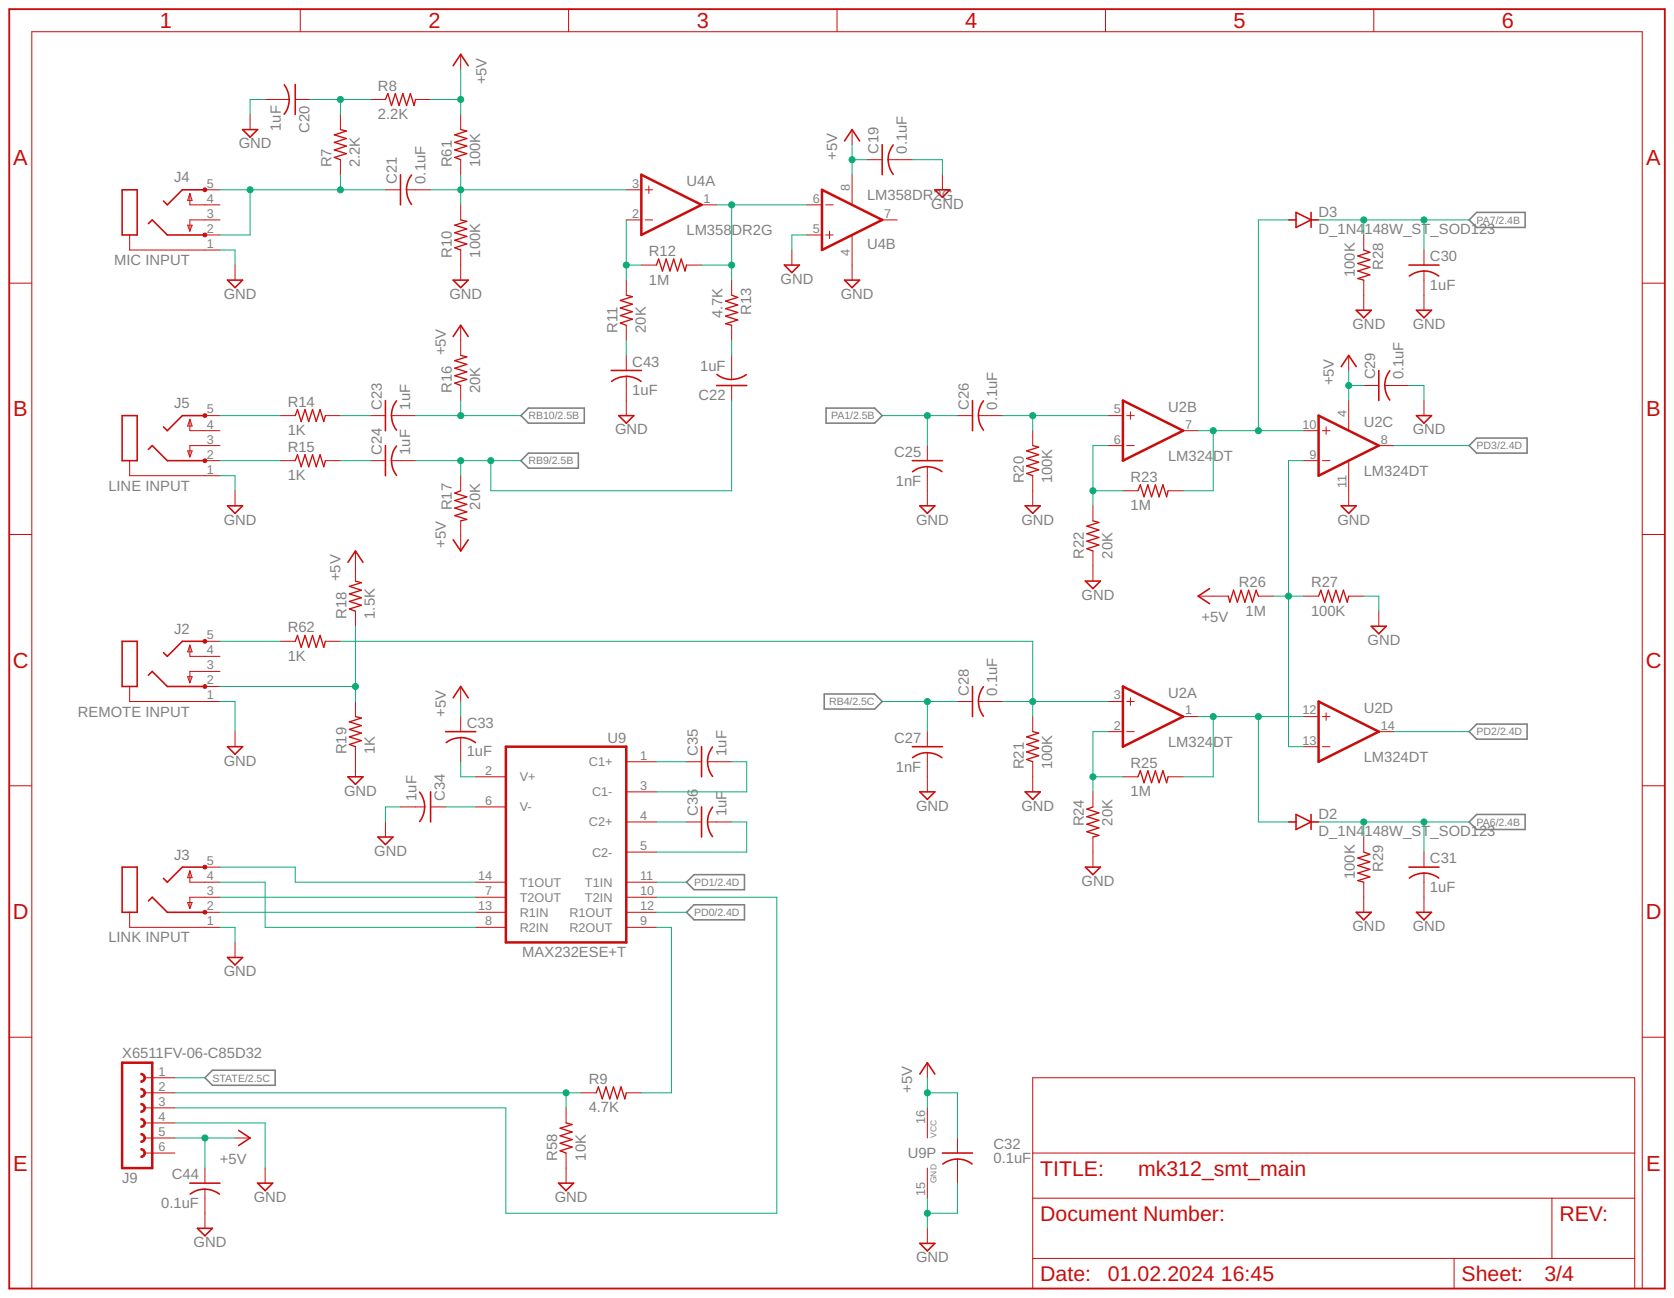
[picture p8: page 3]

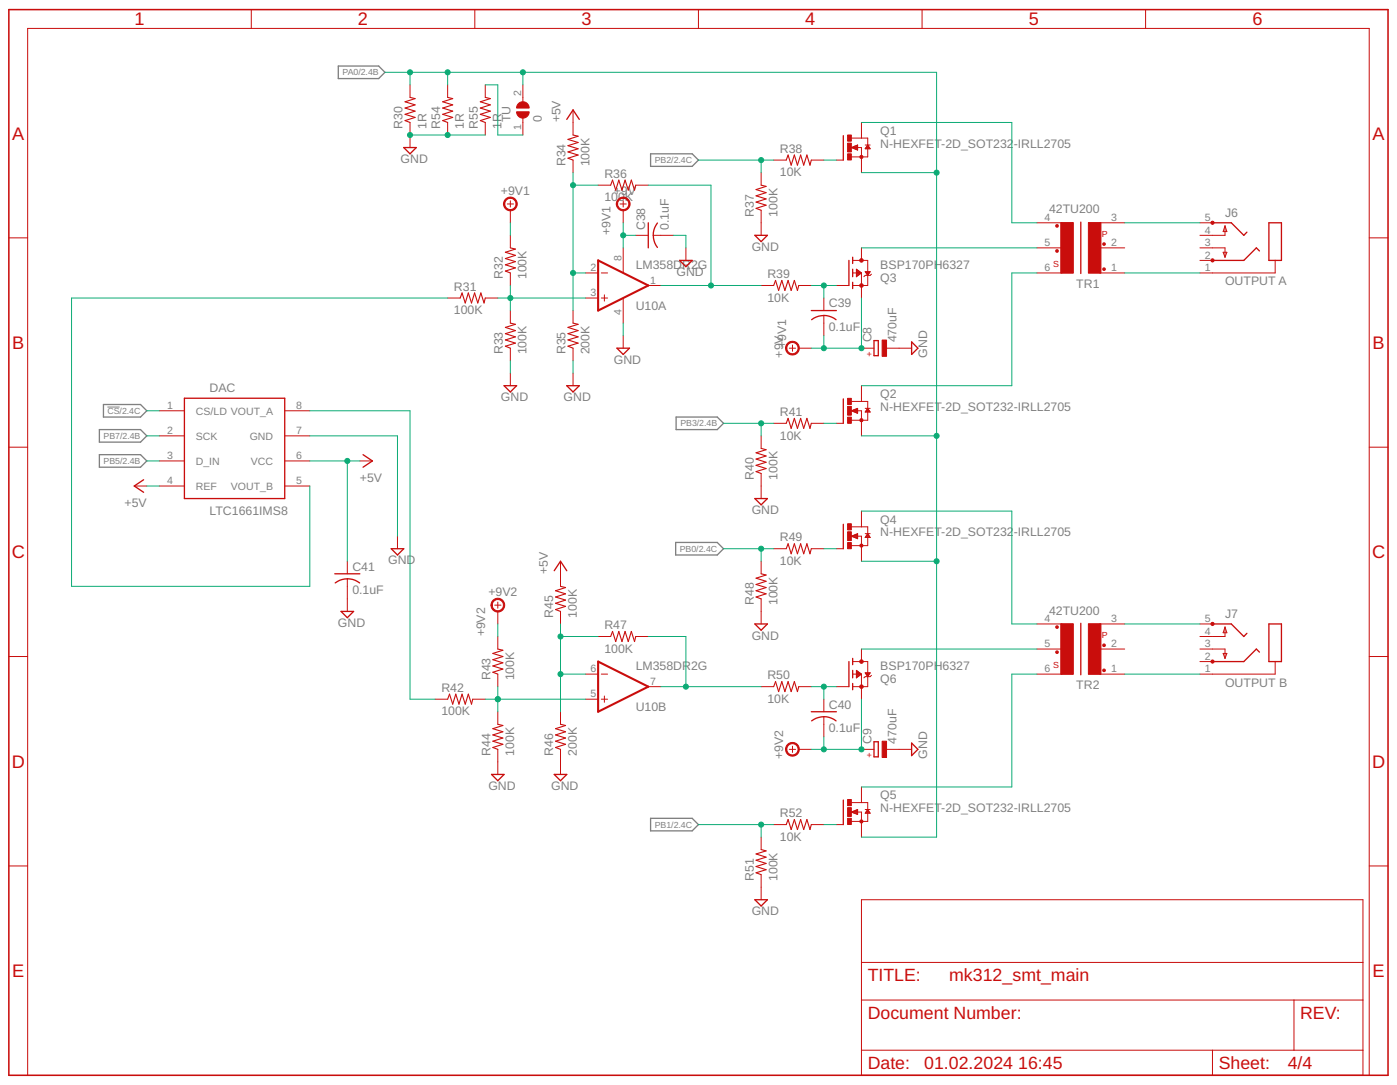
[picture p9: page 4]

100K 10K GND10K 100K GND10K BSP170PH6327 0.1uF GND 100K 100K 100K 100K 200K GND GND 100K +5V 100K 10K GND10K 10K BSP170PH6327 0.1uF 100K 100K 100K 200K GND GND +5V 100K 100K OUTPUT A OUTPUT B 1R GND 100K GND LM358DR2G LM358DR2G 42TU200 42TU200 +9V2 +9V2 0.1uF GND +5V +5V GND 0.1uF GND LTC1661IMS8 470uF GND 470uF GND +9V1 +9V +9V 1R1R0 N-HEXFET-2D_SOT232-IRLL2705 N-HEXFET-2D_SOT232-IRLL2705 N-HEXFET-2D_SOT232-IRLL2705 N-HEXFET-2D_SOT232-IRLL2705 R37 R38 R41 R40 R39 Q3 C39 R36 R33 R32 R34 R35 R31 R48 R49 R52 R50 Q6 C40 R44 R43 R45 R46 R51 R42 54321 J6 54321 J7 R30 R47 23 1 U10A 65 7 U10B 8 4 12 456 3 TR1 12 456 3 TR2 C38 C41 CS/LD 1 SCK 2 D_IN 3 REF 4 GND 7 VCC 6 VOUT_B 5 VOUT_A 8 DAC C8 C9 R54 R55 2 1TU Q1 Q2 Q4 Q5 PB3/2.4B PB1/2.4C PB7/2.4B CS/2.4C PA0/2.4B PB5/2.4B PB2/2.4CPB0/2.4C +9V2 +9V1 +9V1 S P S P ABCDE ABCDE 1 2 3 4 5 6 Date: Sheet: REV: TITLE: Document Number: 01.02.2024 16:45 4/4 mk312_smt_main ++

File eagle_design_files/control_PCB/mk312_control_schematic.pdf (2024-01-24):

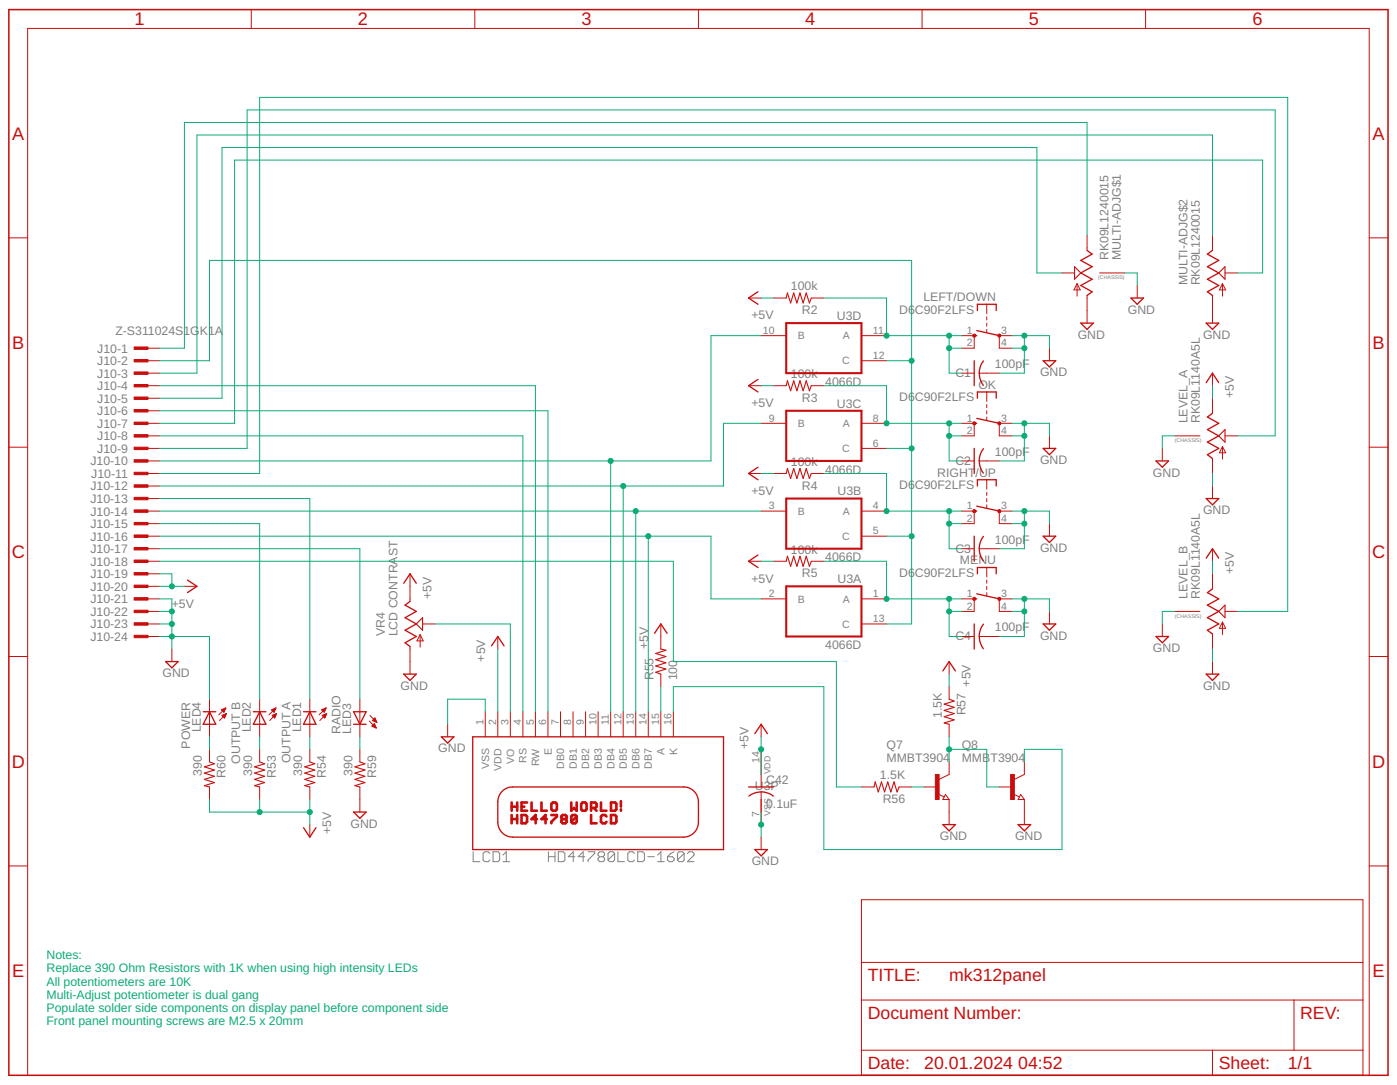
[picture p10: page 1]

Notes: Replace 390 Ohm Resistors with 1K when using high intensity LEDs All potentiometers are 10K

Multi-Adjust potentiometer is dual gang
Populate solder side components on display panel before component side Front panel mounting screws are M2.5 x 20mm

Document Number: | REV:

Date: 20.01.2024 04:52 | Sheet: 1/1

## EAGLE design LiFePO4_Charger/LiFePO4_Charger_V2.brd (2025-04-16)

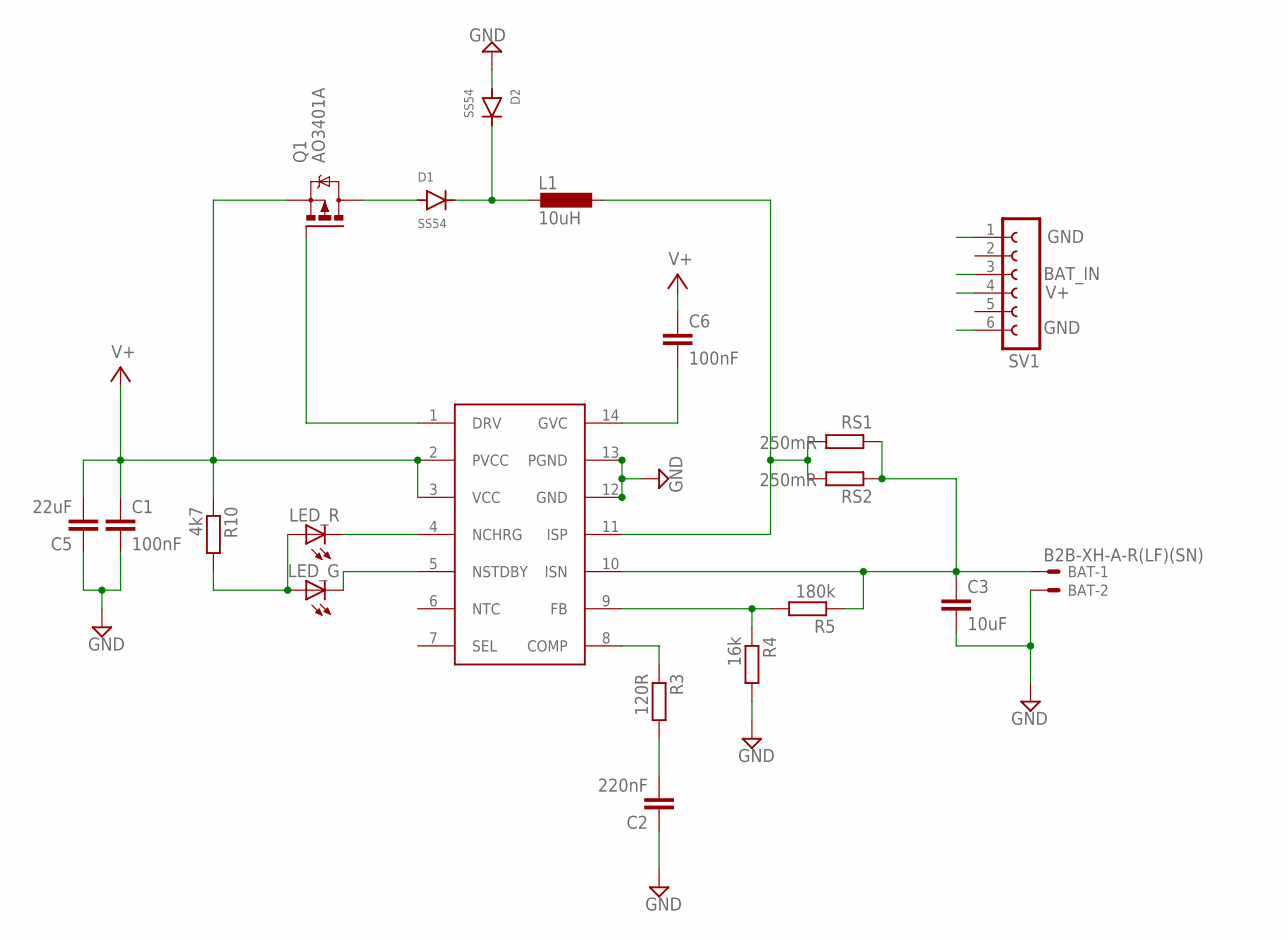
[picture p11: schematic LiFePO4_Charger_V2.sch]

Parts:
BAT: B2B-XH-A-R(LF)(SN); JST-XH-02-PACKAGE-LONG-PAD
C1, C6: 100nF; C0805
C2: 220nF; C0805
C3: 10uF; C0805
C5: 22uF; C0805
D1, D2: SS54; SMA
IC1: SLM6900; TSSOP14
L1: 10uH; FXL0630-100-M
LED_G: LEDCHIPLED_0805; CHIPLED_0805
LED_R: LEDCHIPLED_0805; CHIPLED_0805
Q1: AO3401A; MICRO3
R3: 120R; R0603
R4: 16k; R0805
R5: 180k; R0603
R10: 4k7; R0603
RS1, RS2: 250mR; R1206
SV1: FE06W

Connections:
BAT_IN: BAT.1, C3.1, IC1.10 (ISN), R5.1, RS1.1, RS2.1, SV1.3
GND: BAT.2, C1.2, C2.1, C3.2, C5.1, D2.A, IC1.12 (GND), IC1.13 (PGND), R4.2, SV1.1, SV1.6
unnamed: IC1.4 (NCHRG), LED_R.C
unnamed: IC1.5 (NSTDBY), LED_G.C
unnamed: LED_G.A, LED_R.A, R10.2
unnamed: C6.2, IC1.14 (GVC)
unnamed: IC1.8 (COMP), R3.1
unnamed: C2.2, R3.2
unnamed: D1.C, D2.C, L1.P$1 (1)
unnamed: IC1.9 (FB), R4.1, R5.2
unnamed: D1.A, Q1.3 (D)
unnamed: IC1.1 (DRV), Q1.1 (G)
unnamed: IC1.11 (ISP), L1.P$2 (2), RS1.2, RS2.2
V+: C1.1, C5.2, C6.1, IC1.2 (PVCC), IC1.3 (VCC), Q1.2 (S), R10.1, SV1.4

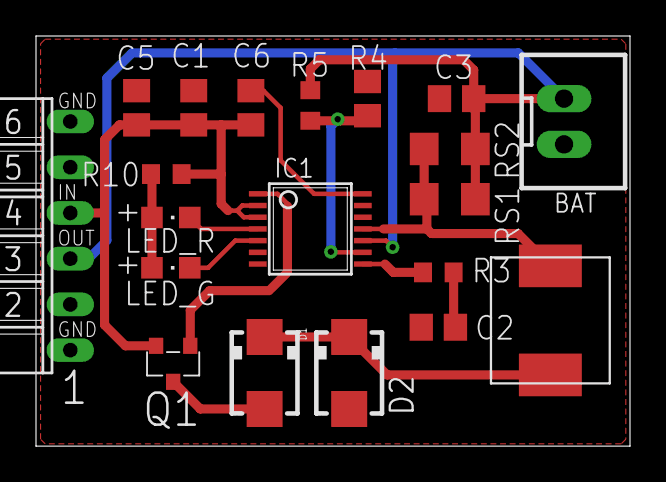
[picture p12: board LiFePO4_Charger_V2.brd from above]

Board: 2 copper layers, 33.0 x 22.8 mm, 20 parts (0 on the bottom side), 14 nets.

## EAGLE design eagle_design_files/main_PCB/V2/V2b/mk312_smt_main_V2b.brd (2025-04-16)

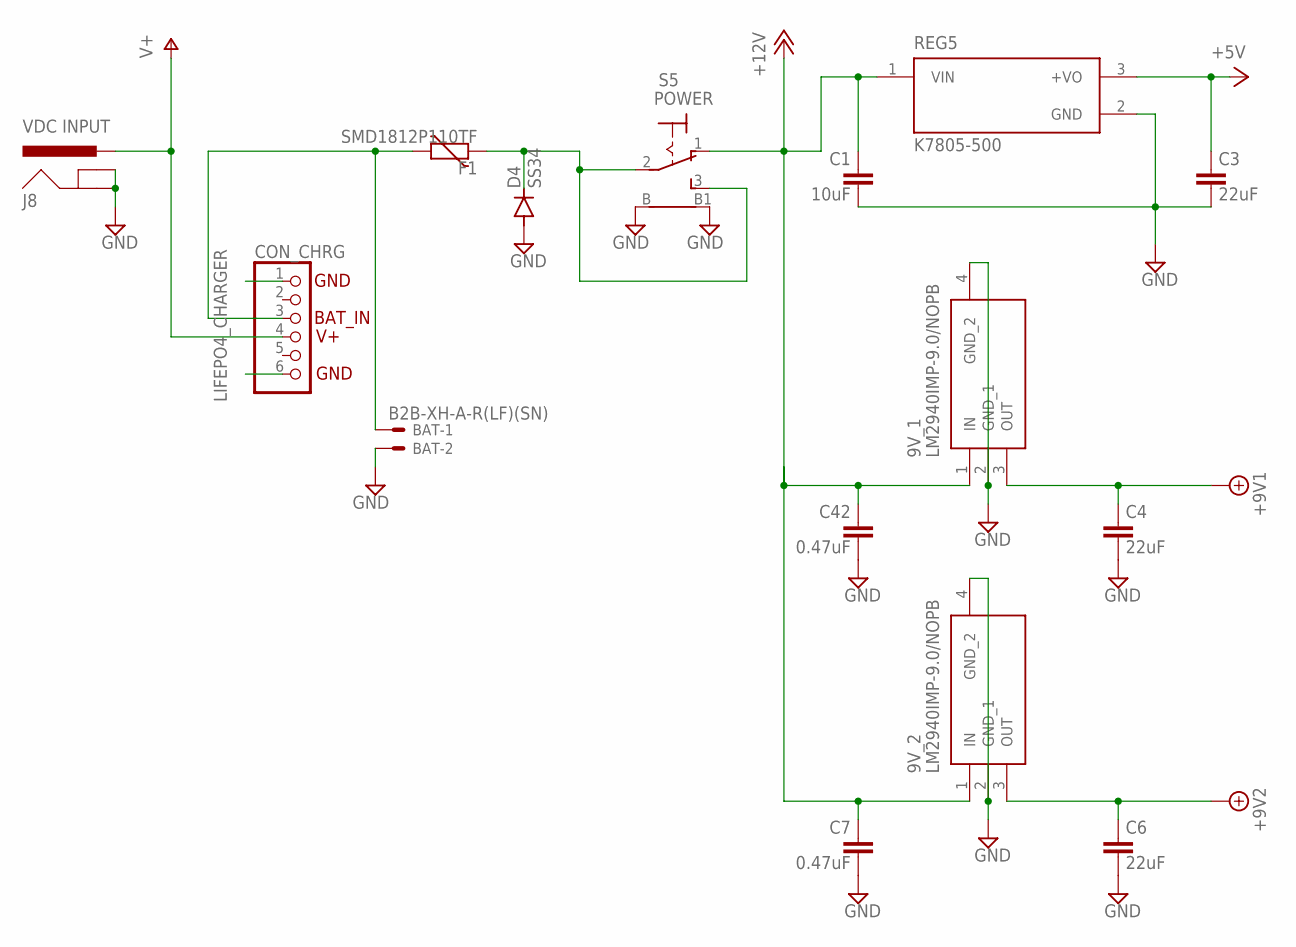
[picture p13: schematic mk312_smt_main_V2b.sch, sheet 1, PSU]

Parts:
9V_1, 9V_2: LM2940IMP-9.0/NOPB; SOT230P700X180-4N
BAT: B2B-XH-A-R(LF)(SN); JST-XH-02-PACKAGE-LONG-PAD
C1: 10uF; C0805
C3, C4, C6: 22uF; C1206
C7, C42: 0.47uF; C0805
CON_CHRG: LIFEPO4_CHARGER
D4: SS34; SMA
F1: SMD1812P110TF; CT/CN1812
J8: VDC INPUT; POWER_JACK_PTH_SLOT
REG5: K7805-500; CONV_K7809M-1000R3
S5: POWER; LPV-1

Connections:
+5V: C3.1, REG5.3 (+VO); also elsewhere on the board
+9V1: 9V_1.3 (OUT), C4.1; also elsewhere on the board
+9V2: 9V_2.3 (OUT), C6.1; also elsewhere on the board
+12V: 9V_1.1 (IN), 9V_2.1 (IN), C1.1, C7.1, C42.1, REG5.1 (VIN), S5.1 (O); also elsewhere on the board
BAT_IN: BAT.1, CON_CHRG.3 (BAT_IN), F1.1
GND: 9V_1.2 (GND_1), 9V_1.4 (GND_2), 9V_2.2 (GND_1), 9V_2.4 (GND_2), BAT.2, C1.2, C3.2, C4.2, C6.2, C7.2, C42.2, CON_CHRG.1 (GND_1), CON_CHRG.6 (GND_2), D4.A, J8.GND, J8.GNDBREAK, REG5.2 (GND), S5.B, S5.B1; also elsewhere on the board
unnamed: D4.C, F1.2, S5.2, S5.3 (S)
V+: CON_CHRG.4 (V+), J8.PWR; also elsewhere on the board

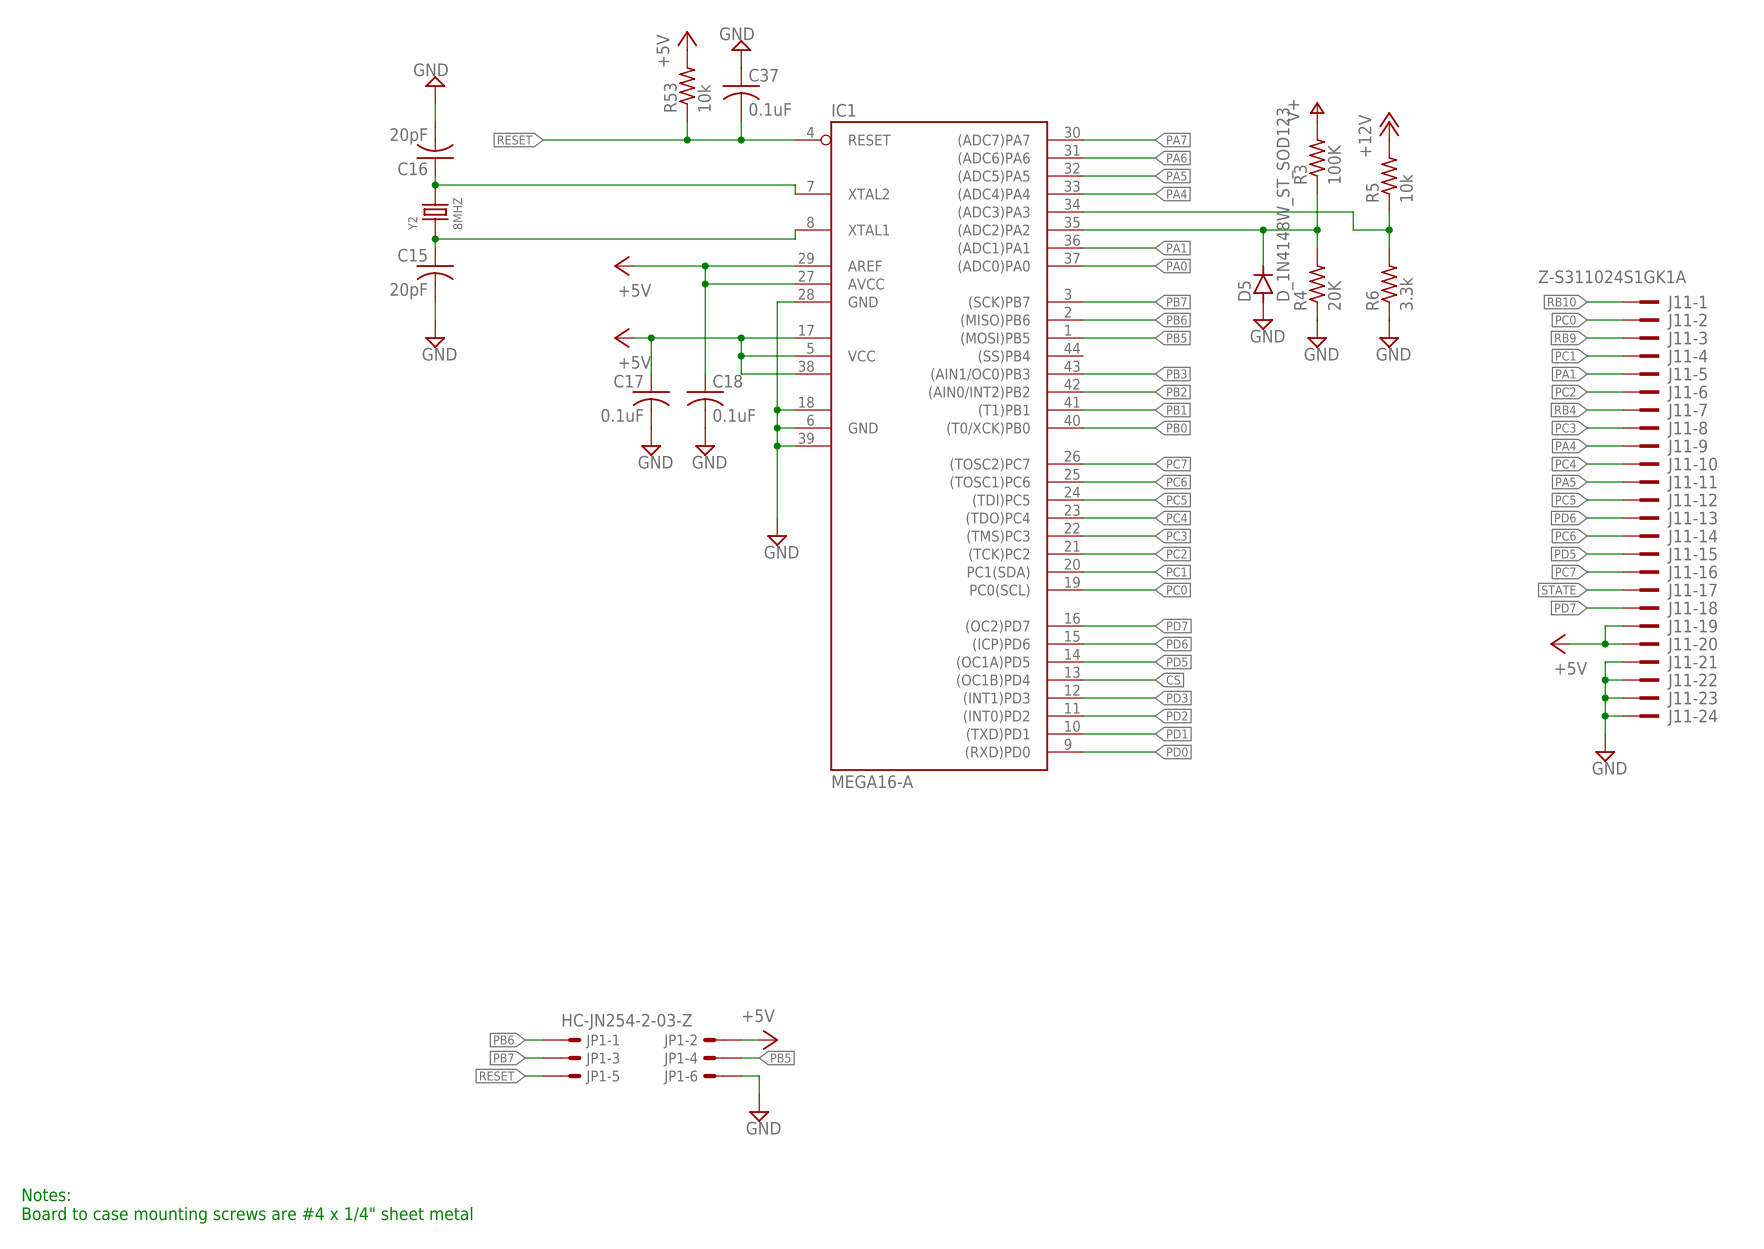
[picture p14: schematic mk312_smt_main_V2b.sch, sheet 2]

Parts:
C15, C16: 20pF; C0603
C17, C18, C37: 0.1uF; C0805
D5: D_1N4148W_ST_SOD123; SOD123
IC1: MEGA16-A; TQFP44
J11: Z-S311024S1GK1A; PAK100/2500-24
JP1: HC-JN254-2-03-Z; 057-006-1
R3: 100K; R0805
R4: 20K; R0805
R5, R53: 10k; R0805
R6: 3.3k; R0805
Y2: 8MHZ; X2-SMD-5.0X3.2X1.3MM

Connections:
!CS: IC1.13 ((OC1B)PD4); also elsewhere on the board
+5V: C17.1, C18.1, IC1.5 (VCC), IC1.17 (VCC1), IC1.27 (AVCC), IC1.29 (AREF), IC1.38 (VCC2), J11.19, J11.20, JP1.2, R53.2; also elsewhere on the board
+12V: R5.2; also elsewhere on the board
GND: C15.2, C16.2, C17.2, C18.2, C37.1, D5.A, IC1.6 (GND), IC1.18 (GND1), IC1.28 (GND), IC1.39 (GND2), J11.21, J11.22, J11.23, J11.24, JP1.6, R4.1, R6.1; also elsewhere on the board
unnamed: C16.1, IC1.7 (XTAL2), Y2.2
unnamed: IC1.34 ((ADC3)PA3), R5.1, R6.2
unnamed: D5.C, IC1.35 ((ADC2)PA2), R3.1, R4.2
unnamed: C15.1, IC1.8 (XTAL1), Y2.1
PA0: IC1.37 ((ADC0)PA0); also elsewhere on the board
PA1: IC1.36 ((ADC1)PA1), J11.5; also elsewhere on the board
PA4: IC1.33 ((ADC4)PA4), J11.9
PA5: IC1.32 ((ADC5)PA5), J11.11
PA6: IC1.31 ((ADC6)PA6); also elsewhere on the board
PA7: IC1.30 ((ADC7)PA7); also elsewhere on the board
PB0: IC1.40 ((T0/XCK)PB0); also elsewhere on the board
PB1: IC1.41 ((T1)PB1); also elsewhere on the board
PB2: IC1.42 ((AIN0/INT2)PB2); also elsewhere on the board
PB3: IC1.43 ((AIN1/OC0)PB3); also elsewhere on the board
PB5: IC1.1 ((MOSI)PB5), JP1.4; also elsewhere on the board
PB6: IC1.2 ((MISO)PB6), JP1.1
PB7: IC1.3 ((SCK)PB7), JP1.3; also elsewhere on the board
PC0: IC1.19 (PC0(SCL)), J11.2
PC1: IC1.20 (PC1(SDA)), J11.4
PC2: IC1.21 ((TCK)PC2), J11.6
PC3: IC1.22 ((TMS)PC3), J11.8
PC4: IC1.23 ((TDO)PC4), J11.10
PC5: IC1.24 ((TDI)PC5), J11.12
PC6: IC1.25 ((TOSC1)PC6), J11.14
PC7: IC1.26 ((TOSC2)PC7), J11.16
PD0: IC1.9 ((RXD)PD0); also elsewhere on the board
PD1: IC1.10 ((TXD)PD1); also elsewhere on the board
PD2: IC1.11 ((INT0)PD2); also elsewhere on the board
PD3: IC1.12 ((INT1)PD3); also elsewhere on the board
PD5: IC1.14 ((OC1A)PD5), J11.15
PD6: IC1.15 ((ICP)PD6), J11.13
PD7: IC1.16 ((OC2)PD7), J11.18
RB4: J11.7; also elsewhere on the board
RB9: J11.3; also elsewhere on the board
RB10: J11.1; also elsewhere on the board
RESET: C37.2, IC1.4 (RESET), JP1.5, R53.1
STATE: J11.17; also elsewhere on the board
V+: R3.2; also elsewhere on the board

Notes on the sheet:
Notes: Board to case mounting screws are #4 x 1/4" sheet metal

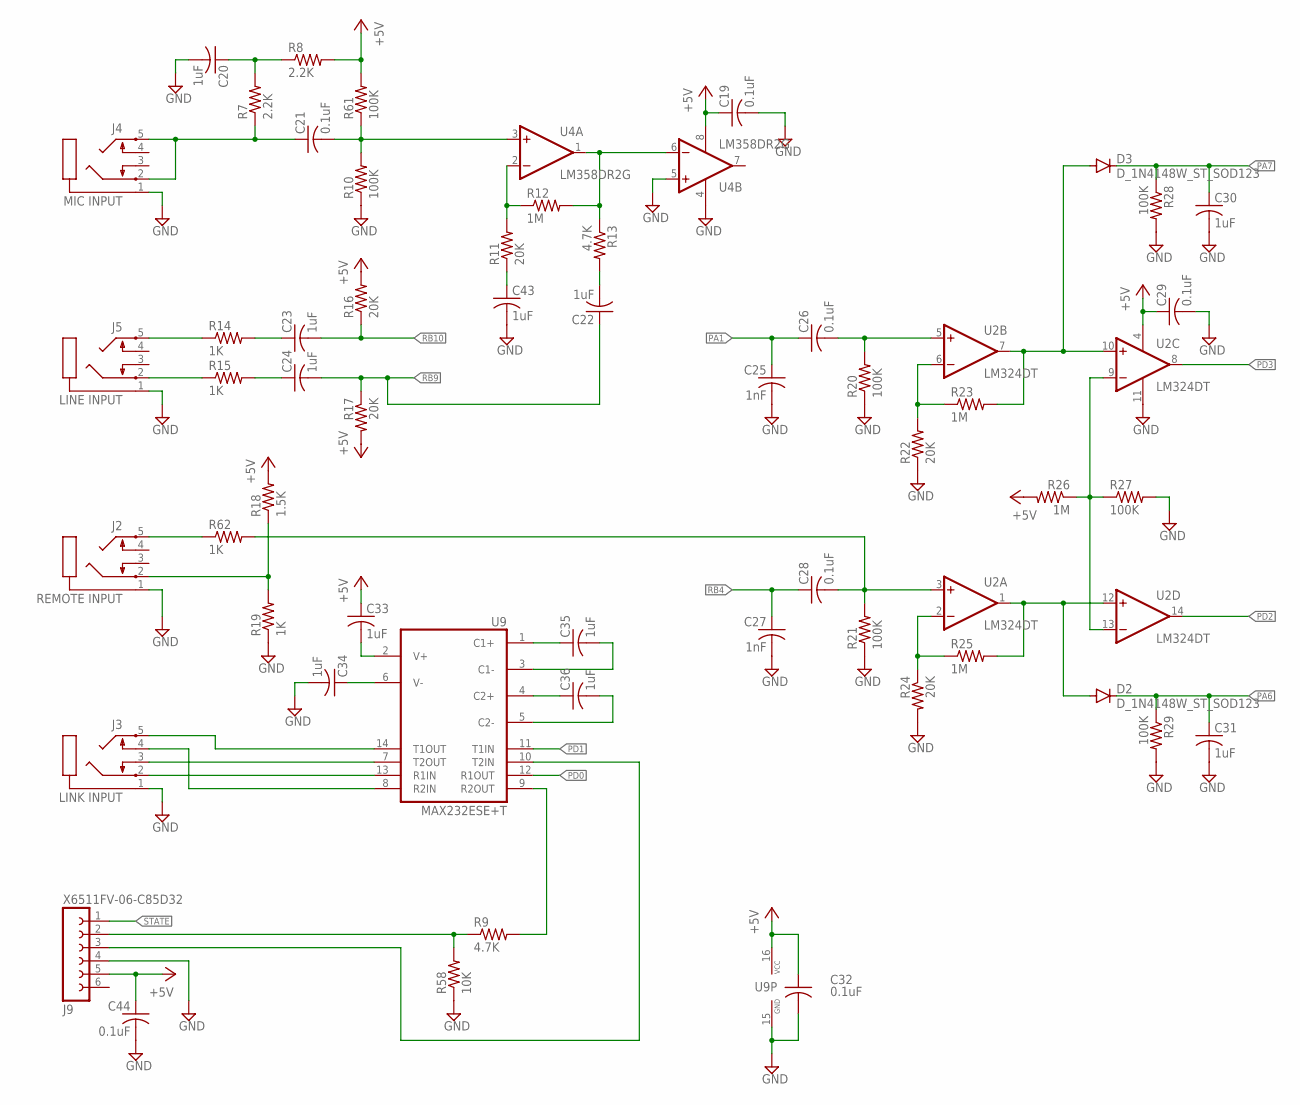
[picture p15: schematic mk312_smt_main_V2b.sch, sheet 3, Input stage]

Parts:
C19, C21, C26, C28, C29, C32, C44: 0.1uF; C0805
C20, C22, C23, C24, C30, C31, C33, C34, C35, C36, C43: 1uF; C0805
C25, C27: 1nF; C0805
D2, D3: D_1N4148W_ST_SOD123; SOD123
J2: REMOTE INPUT; PJ-3062
J3: LINK INPUT; PJ-3062
J4: MIC INPUT; PJ-3062
J5: LINE INPUT; PJ-3062
J9: X6511FV-06-C85D32; FE06
R7, R8: 2.2K; R0805
R9, R13: 4.7K; R0805
R10, R20, R21, R27, R28, R29, R61: 100K; R0805
R11, R16, R17, R22, R24: 20K; R0805
R12, R23, R25, R26: 1M; R0805
R14, R15, R19, R62: 1K; R0805
R18: 1.5K; R0805
R58: 10K; R0805
U2: LM324DT; SO14
U4: LM358DR2G; SO08
U9: MAX232ESE+T; SOP-16

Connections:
+5V: C19.1, C29.1, C32.1, C33.1, C44.1, J9.5, R8.2, R16.2, R17.2, R18.2, R26.2, R61.2, U2.4 (V+), U4.8 (V+), U9.16 (VCC); also elsewhere on the board
GND: C19.2, C20.2, C25.2, C27.2, C29.2, C30.2, C31.2, C32.2, C34.2, C43.2, C44.2, J2.1, J3.1, J4.1, J5.1, J9.4, R10.1, R19.1, R20.1, R21.1, R22.1, R24.2, R27.2, R28.2, R29.2, R58.1, U2.11 (V-), U4.4 (V-), U4.5 (+IN), U9.15 (GND); also elsewhere on the board
unnamed: C28.2, R21.2, R62.2, U2.3 (+IN)
unnamed: R9.2, U9.9 (R2OUT)
unnamed: J3.5, U9.14 (T1OUT)
unnamed: J3.2, U9.13 (R1IN)
unnamed: C43.1, R11.1
unnamed: J2.5, R62.1
unnamed: C35.1, U9.1 (C1+)
unnamed: R24.1, R25.1, U2.2 (-IN)
unnamed: D2.A, R25.2, U2.1 (OUT), U2.12 (+IN)
unnamed: J5.2, R15.1
unnamed: J5.5, R14.1
unnamed: C23.1, R14.2
unnamed: J2.2, R18.1, R19.2
unnamed: R22.2, R23.1, U2.6 (-IN)
unnamed: C35.2, U9.3 (C1-)
unnamed: R26.1, R27.1, U2.9 (-IN), U2.13 (-IN)
unnamed: C26.2, R20.2, U2.5 (+IN)
unnamed: C24.1, R15.2
unnamed: C36.2, U9.5 (C2-)
unnamed: C36.1, U9.4 (C2+)
unnamed: J9.2, R9.1, R58.2
unnamed: D3.A, R23.2, U2.7 (OUT), U2.10 (+IN)
unnamed: C34.1, U9.6 (V-)
unnamed: C21.1, J4.2, J4.5, R7.1
unnamed: C20.1, R7.2, R8.1
unnamed: C21.2, R10.2, R61.1, U4.3 (+IN)
unnamed: R11.2, R12.1, U4.2 (-IN)
unnamed: R12.2, R13.1, U4.1 (OUT), U4.6 (-IN)
unnamed: C22.2, R13.2
unnamed: C33.2, U9.2 (V+)
unnamed: J3.4, U9.8 (R2IN)
unnamed: J3.3, U9.7 (T2OUT)
unnamed: J9.3, U9.10 (T2IN)
PA1: C25.1, C26.1; also elsewhere on the board
PA6: C31.1, D2.C, R29.1; also elsewhere on the board
PA7: C30.1, D3.C, R28.1; also elsewhere on the board
PD0: U9.12 (R1OUT); also elsewhere on the board
PD1: U9.11 (T1IN); also elsewhere on the board
PD2: U2.14 (OUT); also elsewhere on the board
PD3: U2.8 (OUT); also elsewhere on the board
RB4: C27.1, C28.1; also elsewhere on the board
RB9: C22.1, C24.2, R17.1; also elsewhere on the board
RB10: C23.2, R16.1; also elsewhere on the board
STATE: J9.1; also elsewhere on the board

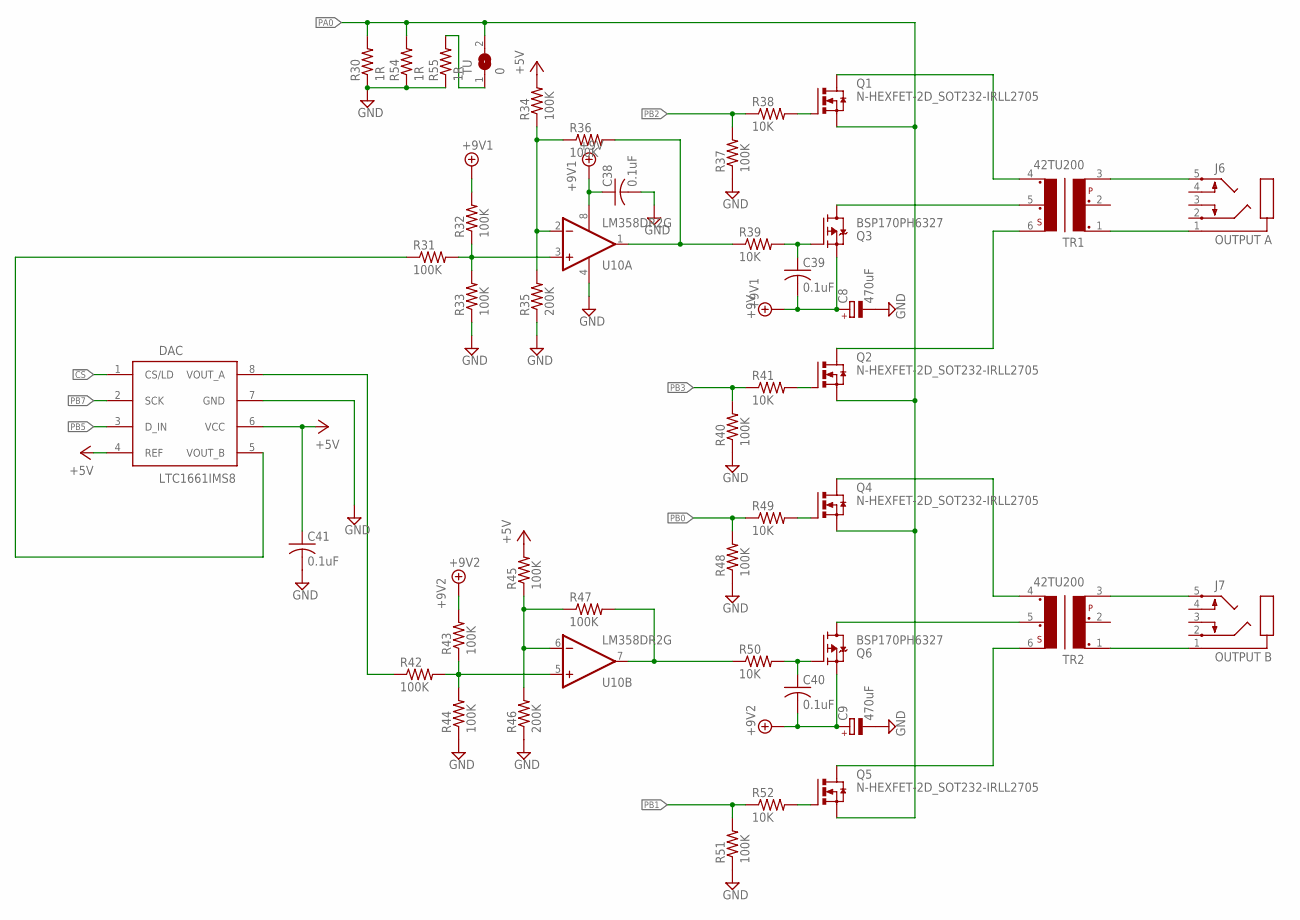
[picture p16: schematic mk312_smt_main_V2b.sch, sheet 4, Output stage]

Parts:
C8, C9: 470uF; 150CLZ-1010
C38, C39, C40, C41: 0.1uF; C0805
DAC: LTC1661IMS8; MSOP8
J6: OUTPUT A; PJ-3062
J7: OUTPUT B; PJ-3062
Q1, Q2, Q4, Q5: N-HEXFET-2D_SOT232-IRLL2705; SOT223
Q3, Q6: BSP170PH6327; SOT230P700X180-4N
R30, R54, R55: 1R; R1206
R31, R32, R33, R34, R36, R37, R40, R42, R43, R44, R45, R47, R48, R51: 100K; R0805
R35, R46: 200K; R0805
R38, R39, R41, R49, R50, R52: 10K; R0805
TR1, TR2: 42TU200; 42TL
TU: 0; SJ
U10: LM358DR2G; SO08

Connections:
!CS: DAC.1 (CS/LD); also elsewhere on the board
+5V: C41.1, DAC.4 (REF), DAC.6 (VCC), R34.2, R45.2; also elsewhere on the board
+9V1: C8.+, C38.1, C39.2, Q3.3 (S), R32.2, U10.8 (V+); also elsewhere on the board
+9V2: C9.+, C40.2, Q6.3 (S), R43.2; also elsewhere on the board
GND: C8.-, C9.-, C38.2, C41.2, DAC.7 (GND), R30.1, R33.1, R35.1, R37.1, R40.1, R44.1, R46.1, R48.1, R51.1, R54.1, R55.1, U10.4 (V-); also elsewhere on the board
unnamed: R55.2, TU.1
unnamed: Q3.2 (D), Q3.4 (D), TR1.5
unnamed: Q6.2 (D), Q6.4 (D), TR2.5
unnamed: J6.1, TR1.1
unnamed: Q1.1 (G), R38.2
unnamed: Q2.1 (G), R41.2
unnamed: C39.1, Q3.1 (G), R39.2
unnamed: R31.2, R32.1, R33.2, U10.3 (+IN)
unnamed: Q4.1 (G), R49.2
unnamed: Q5.1 (G), R52.2
unnamed: J7.1, TR2.1
unnamed: C40.1, Q6.1 (G), R50.2
unnamed: R42.2, R43.1, R44.2, U10.5 (+IN)
unnamed: Q1.2 (D), Q1.4 (D), TR1.4
unnamed: J6.5, TR1.3
unnamed: Q4.2 (D), Q4.4 (D), TR2.4
unnamed: J7.5, TR2.3
unnamed: Q5.2 (D), Q5.4 (D), TR2.6
unnamed: Q2.2 (D), Q2.4 (D), TR1.6
unnamed: R34.1, R35.2, R36.1, U10.2 (-IN)
unnamed: R45.1, R46.2, R47.1, U10.6 (-IN)
unnamed: DAC.5 (VOUT_B), R31.1
unnamed: DAC.8 (VOUT_A), R42.1
PA0: Q1.3 (S), Q2.3 (S), Q4.3 (S), Q5.3 (S), R30.2, R54.2, TU.2; also elsewhere on the board
PB0: R48.2, R49.1; also elsewhere on the board
PB1: R51.2, R52.1; also elsewhere on the board
PB2: R37.2, R38.1; also elsewhere on the board
PB3: R40.2, R41.1; also elsewhere on the board
PB5: DAC.3 (D_IN); also elsewhere on the board
PB7: DAC.2 (SCK); also elsewhere on the board
PFET_A: R36.2, R39.1, U10.1 (OUT)
PFET_B: R47.2, R50.1, U10.7 (OUT)

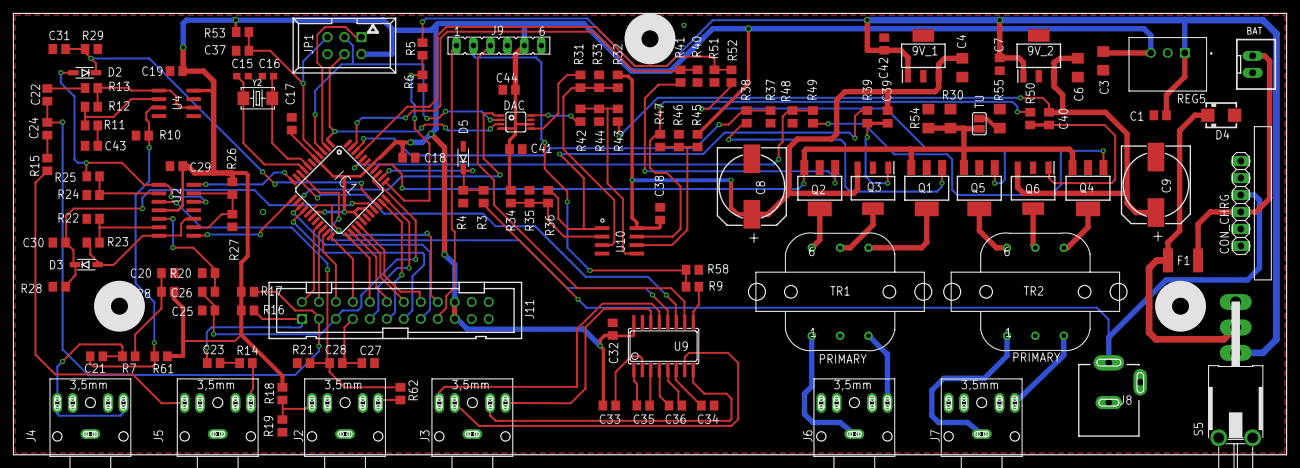
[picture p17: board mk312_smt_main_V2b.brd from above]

Board: 2 copper layers, 190.5 x 66.0 mm, 130 parts (0 on the bottom side), 104 nets.

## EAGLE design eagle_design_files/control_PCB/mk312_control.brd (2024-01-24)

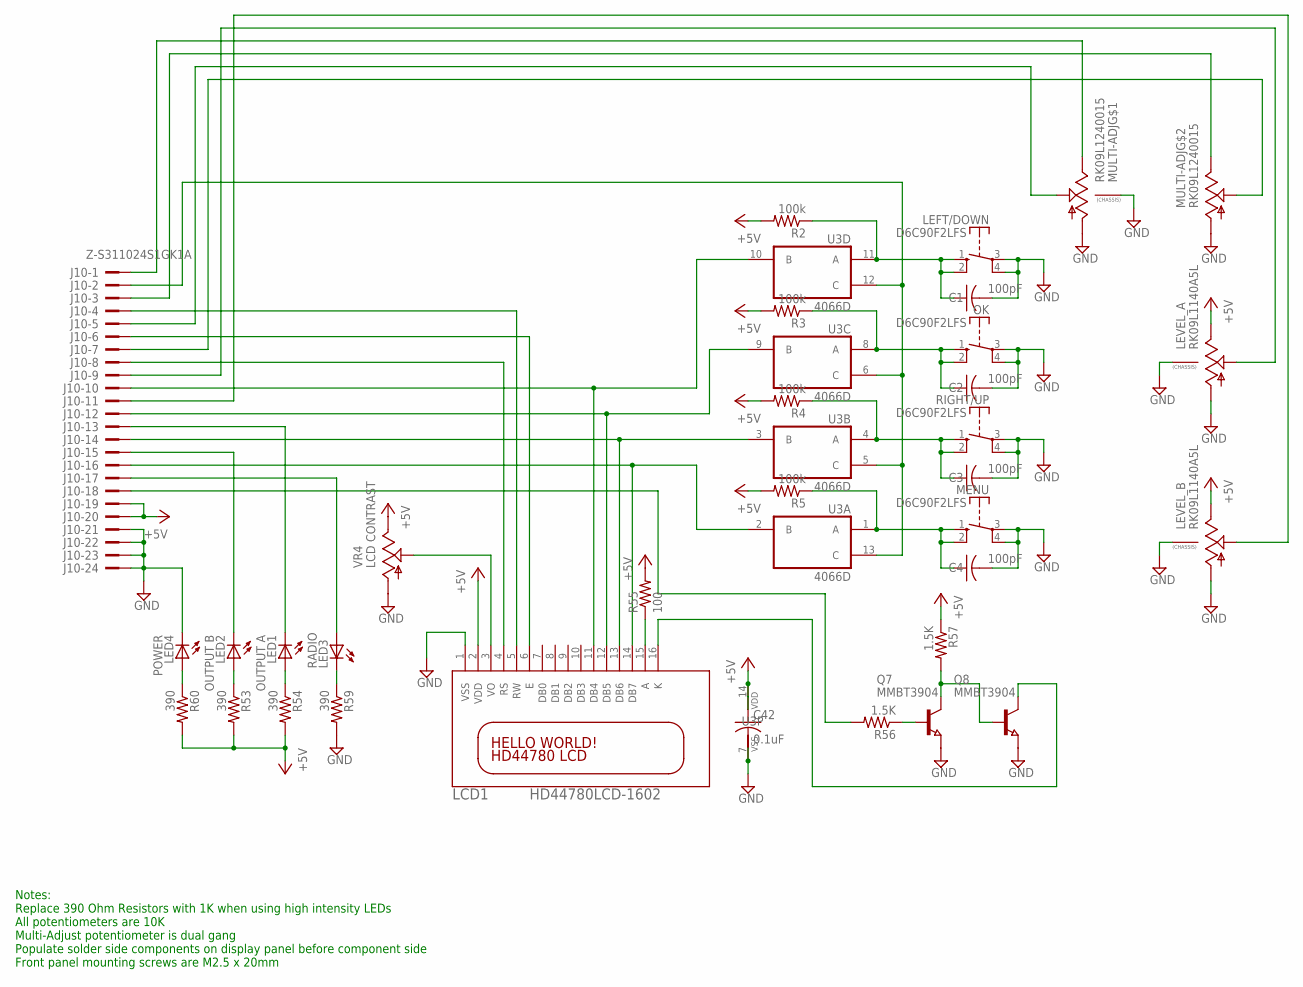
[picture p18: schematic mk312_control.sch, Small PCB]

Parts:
C1, C2, C3, C4: 100pF; C0805
C42: 0.1uF; C0805
J10: Z-S311024S1GK1A; PAK100/2500-24
LCD1: HD44780LCD-1602; LCD1602
LED1: OUTPUT A; LED5MM
LED2: OUTPUT B; LED5MM
LED3: RADIO; LED5MM
LED4: POWER; LED5MM
LEFT/DOWN: D6C90F2LFS; DTE6K
LEVEL_A: RK09L1140A5L; 9MM_SNAP-IN_POT
LEVEL_B: RK09L1140A5L; 9MM_SNAP-IN_POT
MENU: D6C90F2LFS; DTE6K
MULTI-ADJ: RK09L1240015; DUAL_9MM_SNAP-IN_POT
OK: D6C90F2LFS; DTE6K
Q7, Q8: MMBT3904; SOT23
R2, R3, R4, R5: 100k; R0805
R53, R54, R59, R60: 390; R0805
R55: 100; R0805
R56, R57: 1.5K; R0805
RIGHT/UP: D6C90F2LFS; DTE6K
U3: 4066D; SO14
VR4: LCD CONTRAST; B25P

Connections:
+5V: C42.1, J10.19, J10.20, LCD1.2 (VDD), LEVEL_A.3 (E), LEVEL_B.3 (E), R2.2, R3.2, R4.2, R5.2, R53.2, R54.2, R55.2, R57.1, R60.2, U3.14 (VDD), VR4.E
GND: C1.2, C2.2, C3.2, C4.2, C42.2, J10.21, J10.22, J10.23, J10.24, LCD1.1 (VSS), LED4.K (C), LEFT/DOWN.3, LEFT/DOWN.4, LEVEL_A.1 (A), LEVEL_A.CHASSIS2, LEVEL_B.1 (A), LEVEL_B.CHASSIS2, MENU.3, MENU.4, MULTI-ADJ.1 (A), MULTI-ADJ.1B (A), MULTI-ADJ.CHASSIS1, MULTI-ADJ.CHASSIS2, OK.3, OK.4, Q7.2 (E), Q8.2 (E), R59.2, RIGHT/UP.3, RIGHT/UP.4, U3.7 (VSS), VR4.A
unnamed: J10.7, MULTI-ADJ.2B (S)
unnamed: C2.1, OK.1 (S), OK.2 (S), R3.1, U3.8 (A)
unnamed: C1.1, LEFT/DOWN.1 (S), LEFT/DOWN.2 (S), R2.1, U3.11 (A)
unnamed: C3.1, R4.1, RIGHT/UP.1 (S), RIGHT/UP.2 (S), U3.4 (A)
unnamed: J10.3, MULTI-ADJ.3B (E)
unnamed: J10.9, LEVEL_A.2 (S)
unnamed: J10.11, LEVEL_B.2 (S)
unnamed: J10.1, MULTI-ADJ.3 (E)
unnamed: J10.5, MULTI-ADJ.2 (S)
unnamed: LED2.A, R53.1
unnamed: LED1.A, R54.1
unnamed: LCD1.3 (VO), VR4.S
unnamed: LCD1.15 (A), R55.1
unnamed: LED3.K (C), R59.1
unnamed: C4.1, MENU.1 (S), MENU.2 (S), R5.1, U3.1 (A)
unnamed: LED4.A, R60.1
unnamed: Q7.1 (B), R56.1
unnamed: Q7.3 (C), Q8.1 (B), R57.2
unnamed: LCD1.16 (K), Q8.3 (C)
unnamed: J10.17, LED3.A
PC0: J10.2, U3.5 (C), U3.6 (C), U3.12 (C), U3.13 (C)
PC1: J10.4, LCD1.5 (RW)
PC2: J10.6, LCD1.6 (E)
PC3: J10.8, LCD1.4 (RS)
PC4: J10.10, LCD1.11 (DB4), U3.10 (B)
PC5: J10.12, LCD1.12 (DB5), U3.9 (B)
PC6: J10.14, LCD1.13 (DB6), U3.3 (B)
PC7: J10.16, LCD1.14 (DB7), U3.2 (B)
PD5: J10.15, LED2.K (C)
PD6: J10.13, LED1.K (C)
PD7: J10.18, R56.2

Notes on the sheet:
Notes: Replace 390 Ohm Resistors with 1K when using high intensity LEDs All potentiometers are 10K Multi-Adjust potentiometer is dual gang Populate solder side components on display panel before component side Front panel mounting screws are M2.5 x 20mm

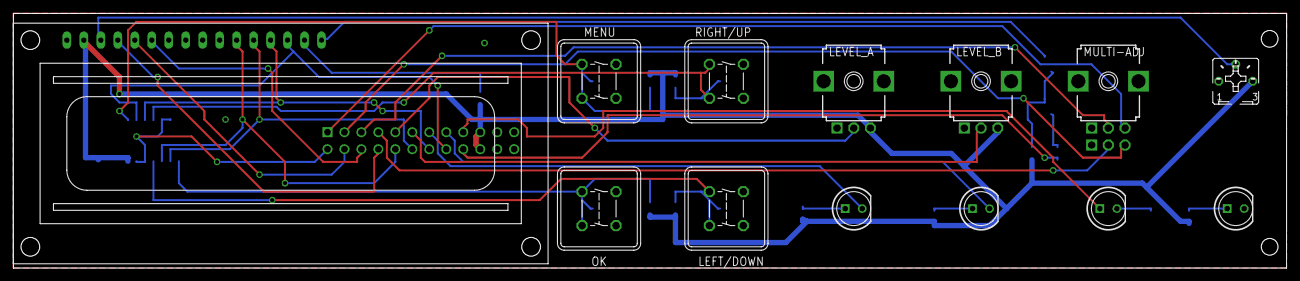
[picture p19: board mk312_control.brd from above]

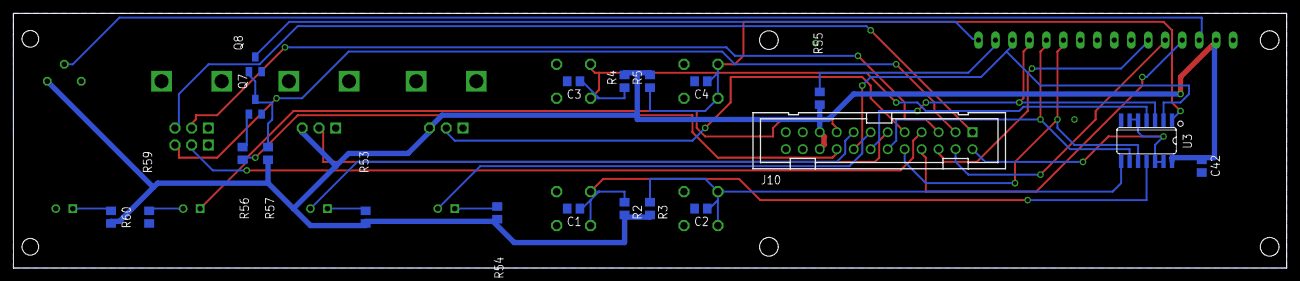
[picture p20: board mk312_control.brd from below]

Board: 2 copper layers, 190.5 x 38.1 mm, 33 parts (20 on the bottom side), 33 nets.

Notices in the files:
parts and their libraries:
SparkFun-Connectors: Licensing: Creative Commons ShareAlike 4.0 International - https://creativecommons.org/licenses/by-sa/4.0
